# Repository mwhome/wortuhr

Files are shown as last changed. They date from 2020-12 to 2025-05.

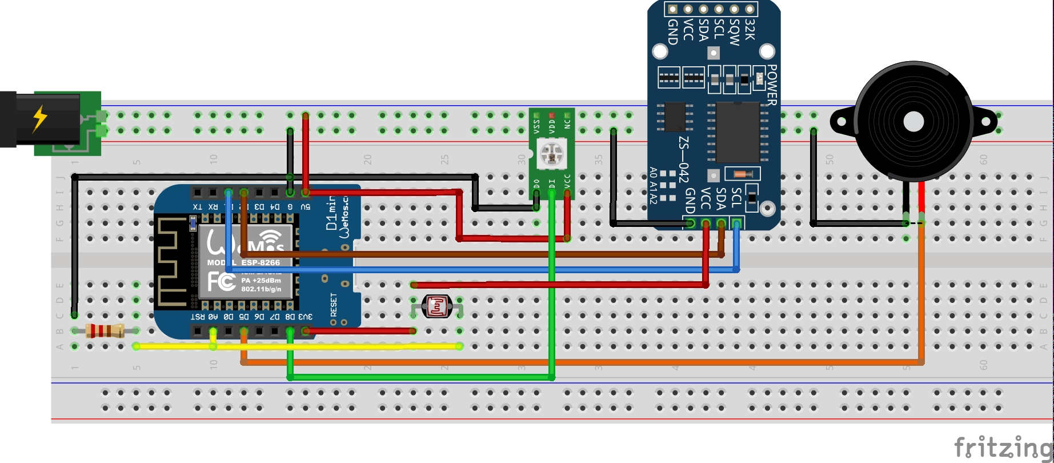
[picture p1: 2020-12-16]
ZeichnungenBilder/WordClockWlankomplett_Steckplatine.jpg

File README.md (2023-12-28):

# wortuhr
Eine Wortuhr auf Basis der Qlockwork von https://github.com/ch570512/Qlockwork und 
https://github.com/bracci/Qlockwork mit verändertem Layout. die ersten LEDs sind die Minuten unten mittig und dann von rechts unten nach rechts oben.

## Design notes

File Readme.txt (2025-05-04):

******************************************************************************
QLOCKWORK
An advanced firmware for a DIY "word-clock".
******************************************************************************

Qlockwork is an ESP8266 (NodeMCU or WeMos D1 mini) firmware (under GPL license) for a so called "word-clock",
initially implemented by ch570512 (thanks Thorsten) and evolved by bracci.

The clock adjusts the time and date once every hour via NTP with a time server on the Internet.
If an RTC is installed, the time of the ESP is also set from the RTC via the SyncProvider.

At startup the clock performs a short self test.
The sequence of the colors should be: red, green, blue and white. If not, your LED driver setup is wrong.
The clock also shows the local IP address it received via DHCP.
Use this address in a browser to access the clocks web site to set it up.

WiFi manager: If the clock can not connect to any WLAN at startup, it turns on an access point(AP).
Connect a mobile phone or tablet to the AP and enter the WLAN credentials. A white "WiFi" is shown on the clock.
On success there are three short beeps and "WiFi" will be green.
If no WLAN is connected or the timeout has expired, there is a long beep and "WiFi" turns red.
After the WLAN timeout the clock works without NTP but you can still control it via its AP.
Without WLAN the clock uses the optional RTC to set the time or if no RTC is present has to be set manually.
In either ways the clocks IP is shown as a textfeed.

WPS: First press the WPS button on your WLAN router, then press the mode button on the QlockWiFive for more than 
5 seconds. While keeping the menu button pressed, don't get confused about the mode first increments (e.g. seconds),
then after 2s jumps to settings and only after 5 seconds "WPS" is shown in blue color on the clock display. Release
the button and wait. On success "WPS" will turn green. At failure it turns red.

Events can be shown at a certain repetition rate (every 5/15/30/60 minutes) on a particular day of the year as an 
animation (e.g. a firework) followed by a textfeed. Up to 8 events can be configured through the web interface. 
Go to settings (gear icon) -> events (birthday cake icon). You can set a text and color as well as an animation
and the desired repetition rate for every event.

Up to 30 animation files (examples in folder /data) can be stored on the file system to be selected and
played on events. Code snippets and files used from manfred-hofmann (thanks Manfred).

Updates of the firmware could be uploaded via USB, OTA or the clocks webserver.
You will find more help and information on how to configure and compile the firmware in "Readme.md" in the zip-archive.
You will also find a circuit diagram, a partslist and some pictures in the "/misc" directory.
All sensors, the RTC and the buzzer are optional.
The clock can run even with an ESP8266 module only.

Warning:    Do not power up the clock from USB only.
            This would blow up the ESP or even the USB port because of high power demand of the LED stripe.
            Always use an external 5V powersupply with at least 3A.

Disclaimer: Qlockwork uses lots of third party libraries.
            We can not guarantee the integrity of these libraries.
            You use the Qlockwork firmware at your own risk.

You can find some more information about QLOCKWORK here:
http://thorsten-wahl.ch/qlockwork/

You can download the latest version of the firmware here:
https://github.com/bracci/Qlockwork

Shop Hardware here:
https://shop.bracci.ch/

Visit this forum for comments, suggestions and bug reports:
http://diskussion.christians-bastel-laden.de/viewtopic.php?t=4230 (QlockWiFive)
http://diskussion.christians-bastel-laden.de/viewtopic.php?f=23&t=2843 (Qlockwork)

******************************************************************************
Top features:
******************************************************************************

Almost no electronics needed. Only an ESP8266 and an LED-stripe.
Optional support for LDR/photo transistor, buzzer, temperature and humidity sensor, IR sensor/remote and buttons.
Support for NeoPixel (RGB and RGBW) LED-stripes.
Support for various horizontal and vertical LED layouts. 5 layouts included.
Webpage to control and configure the clock via WiFi.
WPS functionality for a quick and easy WiFi setup.
Settings via on-screen menu using tactile buttons or IR-remote to control.
Adaptive brightness control when using an LDR or photo transistor.
3 transitions for timechange.
Indoor temperature from RTC, MCP9808 or BME280 or temperature and humidity from DHT or BME280 sensor.
Outdoor temperature and humidity from OpenWeather. You need an APIKey from OpenWeather to use this feature.
Visualisation of moonphase.
Show sunrise and sunset times with animation.
Textfeed and animations for 8 custom events and infos.
Upload up to 30 animation files, usable for events.
Support for 16 frontcovers (original and DIY) in 6 languages.
25 colors.
3 color change modes (incl. mood light -> continuous color change)
99 minute timer.
2 Alarms with weekday selection.
NTP timesync with timezone support.
Automatic adjustment of daylight saving time.
USB and over-the-air firmware updates.
Admin settings page to configure time server, OpenWeather API key & location and the front cover.

******************************************************************************
Pages:
******************************************************************************

Modes:
Time
AM/PM
Seconds
Weekday
Date
Sunrise (needs OpenWeather)
Sunset (needs OpenWeather)
Moonphase
Room temperature (needs RTX or DHT22)
Room humidity (needs DHT22)
Outdoor temperature (needs OpenWeather)
Outdoor humidity (needs OpenWeather)
Timer
LED-test
Red
Green
Blue
White

Settings:
Auto brightness control
Color
Color change
Transition
IT IS
Time
Year
Month
Day
Daily switch off time
Daily switch on time
Fallback timeout back to time

******************************************************************************
Needed libraries: (recommended/tested versions in brackets)
******************************************************************************

Arduino IDE for Windows (1.8.57)
esp8266 by ESP8266 Community (3.1.2)
Arduino_JSON by Arduino (0.1.0)
Adafruit NeoPixel by Adafruit (1.11.0)
Adafruit Unified Sensor by Adafruit (1.1.9)
Adafruit MCP9808 by Adafruit (2.0.0)
Adafruit BME280 by Adafruit (2.4.1)
ArduinoHttpClient by Arduino (0.4.0)
ArduinoOTA by Juraj Andressy (1.0.7)
DHT sensor library by Adafruit (1.4.3)
DS3232RTC by Jack Christensen (2.0.0)
IRremoteESP8266 by Sebastien Warin (2.8.4)
Time by Paul Stoffregen (1.6.1)
WiFiManager by tablatronix/tzapu (0.16.0)
Timezone by Jack Christensen (1.2.4)

******************************************************************************
Compiler-Options: (recommended/tested)
******************************************************************************

Board: "LOLIN(WEMOS) D1 R2 & mini"
CPU Frequency: "80 MHz"
Flash Size: "4M (3M SPIFFS)"
Debug port: "Disabled"
Debug Level: "None"
IwIP Variant: "v2 Lower Memory"
VTables: "Flash"
Exceptions: "Disabled"
Erase Flash: "Only Sketch"
SSL Support: "All SSL ciphers"

******************************************************************************
Misc:
******************************************************************************

For OTA and web-server updates check out:
http://esp8266.github.io/Arduino/versions/2.3.0/doc/ota_updates/readme.html
Don't forget to install Python 2.7 and to select "Add python.exe to path" while installing.

Call "http://your_clocks_ip/update" to upload a new firmware via webbrowser.
Call "http://your_clocks_ip/reset" to restart the ESP.
Call "http://your_clocks_ip/wifiReset" to forget all WiFi networks and credentials.
Call "http://your_clocks_ip/settingsReset" to forget all settings.
Call "http://your_clocks_ip/factoryReset" to forget all settings, WiFi networks and credentials.
Call "http://your_clocks_ip/admin" to open the admin settings page.
Call "http://your_clocks_ip/fs" to open the file system on the ESP and upload animation files, e.g. stored in the repository in the folder "web".

******************************************************************************
Operation manual:
******************************************************************************

Press "on/off" to switch the LEDs on and off.
Press "Settings" to configure the clock via web-site.
Press "Mode" to jump to the next page. Long press enters settings menu. (if enabled by SHOW_MODE_SETTINGS)
Press "Time" to always jump back to the time page.
Press "Plus" to increase LED brightness or to increment value/switch options in settings menu.
Press "Minus" to decrease LED brightness or to decrement value/switch options in settings menu.

*** Modes: *******************************************************************

Time:                               The default mode of the clock. Shows the actual time. :)
Display AM/PM:                      Indicates whether it is AM or PM.
Seconds:                            Shows the seconds.
Weekday:                            Shows the weekday in local language.
Date:                               Shows day and month.
Sunrise:                            Time of sunrise.
Sunset:                             Time of sunset.
Moonphase:                          Shows the moonphase.
Room temperature:                   Display of the measured temperature in the room (only with RTC, MCP9808, BME280 or DHT22).
Room humidity:                      Display of the measured humidity in the room (only with BME280 or DHT22).
Outdoor temperature:                Display the temperature for your location from OpenWeather.
Outdoor humidity:                   Display the humidity for your location from OpenWeather.
Timer:                              Display of the remaining time if a timer is set.
LED-Test:                           Moves a horizontal bar across the display.
Red:                                Set all LEDs to red.
Green:                              Set all LEDs to green.
Blue:                               Set all LEDs to blue.
White:                              Set all LEDs to white.

*** Settings (on-screen): ***************************************************

Auto brightness control (AB):		Enable (EN) or disable (DA) adaptive brightness control.
                                    Brightness will adjust itself in the range of MIN_BRIGHTNESS and brightness.
Color (CO):							Choose one of 25 colors (0~25) for the LEDs.
Color change (CC):					Change the color in intervals.
                                    Do not change (NO), every 5 minutes (5), every hour (60), every day (24), continuously (MD).
Transition (TR):					Choose between none (NO), matrix (MX), move up (UP) or fade (FD) mode transition.
Purist Mode (PT):					Enable (EN) or disable (DA) purist mode. It will be shown every half and full hour anyway.
Show "GSI" (GS):					Enable (EN) or disable (DA) the term GSI for swiss german.
Time (TI ME):						Set the current time in case no internet connectivity is available. The seconds are set to zero.
Year (YY):							Set the current year in case no internet connectivity is available.
Month (MM):							Set the current month in case no internet connectivity is available.
Day (DD):							Set the current day in case no internet connectivity is available.
Daily switch off time (DO FF):		Set the time at which the clock switches off automatically (e.g. at the evening).
Daily switch on time (D ON):		Set the time at which the clock switches on automatically (e.g. at the morning).
Fallback timeout (FB):				Time in seconds to change mode back to time. (0: disabled, max. 60s)

*** Settings (web): **********************************************************

Alarm 1:                            Enable (on) or disable (off) alarm 1.
                                    Time for alarm 1.
                                    Weekdays on which alarm 1 is active.
Alarm 2:                            Enable (on) or disable (off) alarm 2.
                                    Time for alarm 2.
                                    Weekdays on which alarm 2 is active.
Hourly beep:                        Short beep every full hour.
Timer:                              Sets the minute timer. Set to zero to disable a running timer.
Show temperature:                   Enable (on) or disable (off) showing the temperature in time view.
Auto brightness control:      		Enable (on) or disable (off) adaptive brightness control.
                                    Brightness will adjust itself in the range of MIN_BRIGHTNESS and brightness.
Brightness:                         Brightness of the LEDs in percent. The range is MIN_BRIGHTNESS to MAX_BRIGHTNESS.
                                    If ABC is enabled this is the maximum achievable brightness.
Color:                              Choose one of 25 colors for the LEDs.
Colorchange:                        Change the color in intervals.
                                    Do not change (off), every 5 minutes (five), every hour (hour), every day (day), continuously (mood).
Transition:                         Choose between fast, move or fade mode transition.
Fallback timeout:           		Time in seconds to change mode back to time. (0: disabled, max. 60s)
Daily switch off time:              Set the time the clock turns itself off at night.
Daily switch on time:               Set the time the clock turns itself on at day.
Purist Mode:                       	Enable (on) or disable (off) purist mode. It will be shown every half and full hour anyway.
Show "GSI":							Enable (on) or disable (off) the term GSI for swiss german.
Set date/time:                      Date and time of the clock. The seconds are set to zero if you press save.

*** Admin Settings (web): ****************************************************
Time server:						URL of the preferred time server
OpenWeather API key:				API key provided by Openweather allowing to get weather information through API.
OpenWeather location				Location which the weather information should refer to. Needs to follow the location format of 
									OpenWeather, e.g. "Bern, CH". Check out on https://openweathermap.org/ and check for your city.
Language/dialect:					Language or dialect of the used front cover.
Light sensor column no.				Column number in which the light sensor is installed.			
Light sensor row no.				Row number in which the light sensor is installed.

******************************************************************************
Configuration.h - Software settings:
******************************************************************************

#define PRODUCT_NAME                The name of the clock.
#define WEBSITE_TITLE               Title on top of the clocks webpage.
#define WIFI_SETUP_TIMEOUT          Time in seconds set up the WiFiManager or search for a WLAN.
                                    If no WLAN is connected the clock enters AP mode.
                                    You can control the clock if you connect your phone or tablet to this accesspoint.
                                    On Android you have to tell the phone that it's ok to have no internet.
#define WIFI_AP_PASS                The password for the AP. At least 8 characters. Default is "12345678".
#define OTA_PASS                    Password for "Over the Air" updates. Default is "1234".
#define NTP_SERVER                  NTP server to be queried.
#define NTP_TIMEOUT                 Milliseconds to wait for NTP server to answer.
#define WIFI_BEEPS                  Beep 3 times if WIFI is conneced, if not, beep one time on startup.
#define SHOW_IP                     Show local IP at startup. Use this in the browser to access the clocks menue.
#define NONE_TECHNICAL_ZERO         Displays the zero without the diagonal line.
#define AUTO_MODECHANGE_TIME        Time in seconds to wait between switching from time to temperature.
#define FEED_SPEED                  Feed delay in milliseconds. 120 is a good start.
#define SUNSET_SUNRISE_SPEED        Milliseconds delay between sunrise screen -> sunrise time and sunset screen -> sunset time
#define ALARM_LED_COLOR             Color of the alarm LED. If not defined the display color will be used.
                                    The possible colors are:
                                    WHITE, RED, RED_25, RED_50, ORANGE, YELLOW, YELLOW_25, YELLOW_50, GREENYELLOW,
                                    GREEN, GREEN_25, GREEN_50, MINTGREEN, CYAN, CYAN_25, CYAN_50, LIGHTBLUE, BLUE,
                                    BLUE_25, BLUE_50, VIOLET, MAGENTA, MAGENTA_25, MAGENTA_50, PINK.
#define ABUSE_CORNER_LED_FOR_ALARM  Use the upper right minute LED as alarm LED. Only works if ALARM_LED_COLOR is defined.
                                    If no alarm or timer is set the LED is used as expected.
#define DEDICATION                  Show a text on the clocks webpage.

#define POWERON_SELFTEST            Test LEDs at startup. Colors are: white, red, green, blue. In this order.
#define SHOW_MODE_AMPM              Show AM/PM.
#define SHOW_MODE_SECONDS           Show seconds.
#define SHOW_MODE_WEEKDAY           Show weekday.
#define SHOW_MODE_DATE              Show date.
#define SHOW_MODE_MOONPHASE         Show moonphase.
#define SHOW_MODE_SUNRISE_SUNSET    Show sunrise and sunset times.
#define SHOW_MODE_TEST              Show tests.
#define SHOW_MODE_SETTINGS	        Show on-display settings menu.

#define APIKEY                      Enables OpenWeather features.
#define DEFAULT_LOCATION            Default location for OpenWeather.

#define TIMEZONE_*                  The time zone in which the clock is located. Important for the UTC offset and the
                                    summer/winter time change.
#define LANGUAGE_*					Language of the web interface.

******************************************************************************
Configuration.h - Hardware settings:
******************************************************************************

#define ESP_LED                     Displays the function using the LED on the ESP. It flashes once a second.

#define ONOFF_BUTTON                Use a hardware on/off-button.
#define MODE_BUTTON                 Use a hardware mode-button.
#define TIME_BUTTON                 Use a hardware time-button.
#define PLUS_BUTTON					Use a hardware plus-button.
#define MINUS_BUTTON				Use a hardware minus-button.

#define SENSOR_DHT22                Use a DHT22 sensor module (not the plain sensor) for room temperature and humidity.
#define DHT_TEMPERATURE_OFFSET      Sets how many degrees the measured room temperature (+ or -) should be corrected.
#define DHT_HUMIDITY_OFFSET         Sets how many degrees the measured room humidity (+ or -) should be corrected.

#define SENSOR_MCP9808				Use a MCP9808 sensor or sensor module.
#define MCP_TEMPERATURE_OFFSET		Sets how many degrees the measured room temperature (+ or -) should be corrected.

#define SENSOR_BME					Use a BME280 sensor or sensor module.
#define BME_TEMPERATURE_OFFSET		Sets how many degrees the measured room temperature (+ or -) should be corrected.
#define BME_HUMIDITY_OFFSET         Sets how many degrees the measured room humidity (+ or -) should be corrected.

#define RTC_BACKUP                  Use an RTC as backup and room temperature.
#define RTC_TEMPERATURE_OFFSET      Sets how many degrees the measured room temperature (+ or -) should be corrected.

#define LDR                         Use an LDR for adaptive brightness control (ABC).
#define LDR_IS_INVERSE              Combined with #define LDR inverses the value of the LDR.
#define LDR_HYSTERESIS              Brightness control from a deviation in the range from 0 to 1023. Default: 40.
                                    If your display is flickering increase this value.
#define MIN_BRIGHTNESS              Minimum brightness of LEDs ranging from 0 to 255. Default: 20.
#define MAX_BRIGHTNESS              Maximum brightness of LEDs ranging from 0 to 255. Default 255.
                                    Your powersupply has to support this brightness.
#define BRIGHTNESS_SELFTEST         Brightness of the LEDs while in testmode to not overload the powersupply.

#define BUZZER                      Use a buzzer to make noise for alarmtime and timer.
                                    If not defined all alarmfunctions are disabled.
#define BUZZTIME_ALARM_1            Maximum time in seconds for alarm 1 to be active when not turned off manually.
#define BUZZTIME_ALARM_2            Maximum time in seconds for alarm 2 to be active when not turned off manually.
#define BUZZTIME_TIMER              Maximum time in seconds for the timer alarm to be active when not turned off manually.

#define IR_REMOTE                   Use an IR remote control.
#define IR_LETTER_OFF               Turns off the LED behind the IR sensor permanently. This improves IR reception.
#define IR_CODE_*                   Any remote control can be used. 6 keys are supported.
                                    Press a button on the remote control in front of the clock.
                                    Then write the code displayed in the serial console to the file "Configuration.h".
                                    If you see more than one try the code which is changing from button to button.
                                    DEBUG has to be defined to show you the code.

#define NEOPIXEL_RGB                Select if your LEDs are RGB only.
#define NEOPIXEL_RGBW               Select if your LEDs have a distinct white channel (RGBW).

#define NEOPIXEL_TYPE               Specifies the NeoPixel driver. 400kHz, 800kHz, GRB, RGB, GRBW, RGBW...
                                    See \libraries\Adafruit_NeoPixel.h for help.

#define LED_LAYOUT_HORIZONTAL_1     Horizontal and corner and alarm LEDs at the end of the strip. (As seen from the front.)

111                    114                    112
   000 001 002 003 004 005 006 007 008 009 010
   021 020 019 018 017 016 015 014 013 012 011
   022 023 024 025 026 027 028 029 030 031 032
   043 042 041 040 039 038 037 036 035 034 033
   044 045 046 047 048 049 050 051 052 053 054
   065 064 063 062 061 060 059 058 057 056 055
   066 067 068 069 070 071 072 073 074 075 076
   087 086 085 084 083 082 081 080 079 078 077
   088 089 090 091 092 093 094 095 096 097 098
   109 108 107 106 105 104 103 102 101 100 099
110                                           113

#define LED_LAYOUT_VERTICAL_1       Vertical and corner and alarm LEDs (almost) within the strip. (As seen from the front.)

000                    114                    102
   001 021 022 041 042 061 062 081 082 101 103
   002 020 023 040 043 060 063 080 083 100 104
   003 019 024 039 044 059 064 079 084 099 105
   004 018 025 038 045 058 065 078 085 098 106
   005 017 026 037 046 057 066 077 086 097 107
   006 016 027 036 047 056 067 076 087 096 108
   007 015 028 035 048 055 068 075 088 095 109
   008 014 029 034 049 054 069 074 089 094 110
   009 013 030 033 050 053 070 073 090 093 111
   010 012 031 032 051 052 071 072 091 092 112
011                                           113

#define LED_LAYOUT_VERTICAL_2       Vertical and corner and alarm LEDs at the end of the strip. (As seen from the front.)

112                    111                    110
   009 010 029 030 049 050 069 070 089 090 109
   008 011 028 031 048 051 068 071 088 091 108
   007 012 027 032 047 052 067 072 087 092 107
   006 013 026 033 046 053 066 073 086 093 106
   005 014 025 034 045 054 065 074 085 094 105
   004 015 024 035 044 055 064 075 084 095 104
   003 016 023 036 043 056 063 076 083 096 103
   002 017 022 037 042 057 062 077 082 097 102
   001 018 021 038 041 058 061 078 081 098 101
   000 019 020 039 040 059 060 079 080 099 100
113                                           114

#define LED_LAYOUT_VERTICAL_3       Vertical and corner and alarm LEDs at the end of the strip. (As seen from the front.)

111                    114                    110
   009 010 029 030 049 050 069 070 089 090 109
   008 011 028 031 048 051 068 071 088 091 108
   007 012 027 032 047 052 067 072 087 092 107
   006 013 026 033 046 053 066 073 086 093 106
   005 014 025 034 045 054 065 074 085 094 105
   004 015 024 035 044 055 064 075 084 095 104
   003 016 023 036 043 056 063 076 083 096 103
   002 017 022 037 042 057 062 077 082 097 102
   001 018 021 038 041 058 061 078 081 098 101
   000 019 020 039 040 059 060 079 080 099 100
112                                           113

#define LED_LAYOUT_VERTICAL_4       Vertical and corner and alarm LEDs at the end of the strip. (As seen from the front.)
#define LED_LAYOUT_VERTICAL_4_XXL	Indentically with LED_LAYOUT_VERTICAL_4 but with 2 LEDs per letter.

011                    114                    113
   010 012 031 032 051 052 071 072 091 092 112
   009 013 030 033 050 053 070 073 090 093 111
   008 014 029 034 049 054 069 074 089 094 110
   007 015 028 035 048 055 068 075 088 095 109
   006 016 027 036 047 056 067 076 087 096 108
   005 017 026 037 046 057 066 077 086 097 107
   004 018 025 038 045 058 065 078 085 098 106
   003 019 024 039 044 059 064 079 084 099 105
   002 020 023 040 043 060 063 080 083 100 104
   001 021 022 041 042 061 062 081 082 101 103
000                                           102

#define LED_LAYOUT_VERTICAL_5       Vertical and corner and alarm LEDs (almost) within the strip. (As seen from the front.)

000                    062                    103
   001 021 022 041 042 061 063 082 083 102 104
   002 020 023 040 043 060 064 081 084 101 105
   003 019 024 039 044 059 065 080 085 100 106
   004 018 025 038 045 058 066 079 086 099 107
   005 017 026 037 046 057 067 078 087 098 108
   006 016 027 036 047 056 068 077 088 097 109
   007 015 028 035 048 055 069 076 089 096 110
   008 014 029 034 049 054 067 075 090 095 111
   009 013 030 033 050 053 071 074 091 094 112
   010 012 031 032 051 052 072 073 092 093 113
011                                           114

******************************************************************************
Configuration.h - Misc:
******************************************************************************

#define DEBUG                       Show debug infos in the serial console.
#define DEBUG_WEB                   Show debug infos on the web page.
#define DEBUG_MATRIX                Renders the output of the matrix for the German front in the serial console.
#define DEBUG_FPS                   Show number of loops per second in the serial console.

#define SYSLOGSERVER                Turn logging to a syslogserver on/off.
#define SYSLOGSERVER_SERVER         Address of the syslogserver.
#define SYSLOGSERVER_PORT           Port of the syslogserver.

#define UPDATE_INFO_*               The update info periodically anonymously checks if there is a firmwareupdate
                                    available. No user data is send to the host. Comment if you do not want this info.
#define UPDATE_INFOSERVER           Address of the updateinfo server.
#define UPDATE_INFOFILE             Path and name of the updateinfo file.

#define SERIAL_SPEED                Serial port speed for the console.

******************************************************************************
Web-API:
******************************************************************************

http://your_clocks_ip/commitSettings?
a1=0                                Alarm 1 on [1] or off [0]
a1t=hh:mm                           Alarm 1 hour [hh] and minute [mm]
a1w1=2                              Set Sunday
a1w2=4                              Set Monday
a1w3=8                              Set Tuesday
a1w4=16                             Set Wednesday
a1w5=32                             Set Thursday
a1w6=64                             Set Friday
a1w7=128                            Set Saturday
a2=0                                Alarm 2 on [1] or off [0]
a2t=hh:mm                           Alarm 2 hour [hh] and minute [mm]
a2w1=2                              Set Sunday
a2w2=4                              Set Monday
a2w3=8                              Set Tuesday
a2w4=16                             Set Wednesday
a2w5=32                             Set Thursday
a2w6=64                             Set Friday
a2w7=128                            Set Saturday
hb=0                                Hourly beep on [1] or off [0]
ti=0                                Timer in minutes
mc=0                                Modechange on [1] or off [0]
ab=1                                ABC on [1] or off [0]
br=50                               Brightness in percent
co=14                               Number of the LEDs color. See Colors.h
cc=0                                Number of colorchange. See Colors.h
tr=1                                Number of transition. See Modes.h
to=15                               Timeout in seconds
no=hh:mm                            Night off hour [hh] and minute [mm]
do=hh:mm                            Day on hour [hh] and minute [mm]
ii=1                                Purist mode on [1] or off [0]
gs=0								Enable [1] or disable [0] the term GSI for swiss german
st=YYYY-MM-DDThh:mm                 Set time and date

http://your_clocks_ip/commitEvents?
ev0t=Happy+Birthday					Feed text (max. 30 characters) for event no.0
ev0ani=0							Animation name [0~29] for event no.0
ev0d=YYYY-MM-DD						Date for event no.0
ev0c=0								Color [0~24] for event no.0
ev0rep=4							Repetition rate [0~4] for event no.0
...
ev0t=Happy+Birthday					Feed text (max. 30 characters) for event no.7
ev0ani=0							Animation name [0~29] for event no.7
ev0d=YYYY-MM-DD						Date for event no.7
ev0c=0								Color [0~24] for event no.7
ev7rep=4							Repetition rate [0~4] for event no.7

http://your_clocks_ip/commitAdminSettings?
adts=pool.ntp.org                   URL of preferred time server
adwk=123...                         API key used for OpenWeather
adwl=bern, ch						Openweather location
adfc=0								Front cover [0~13]

http://your_clocks_ip/showText?
buzzer=1                            Number of times the buzzer will beep before showing the text (optional)
color=0                             Color of the textfeed, 0 to 24 (optional)
text=text                           Set text of feed, max. 80 characters
                                    e.g.: http://192.168.1.10/showText?buzzer=2&color=1&text=Instant%20text%20on%20Qlockwork!

http://your_clocks_ip/control?
mode=0                              Set clock to mode=0 (time), mode=1 (am/pm), ...
                                    mode=17 (off, if all other modes are enabled) -- see modes.h and count.
                                    e.g.: http://192.168.1.10/control?mode=6

******************************************************************************
Changelog:
******************************************************************************
20240227:
Reverted special cases for HW v1.2. Made a separate branch (V1_2wButtons) for HW v1.2 which uses buttons.

20240214:
Added pin definitions for button and buzzer on HW v1.2.

20240206:
Introduced layout and board for QlockWiFive Mini v1.1.
Fixed bug in SWISS GERMAN ZH dialect.

20231219:
Introduced settingsReset and factoryReset. 

20231218:
Introduced settings for LDR position.
Fixed bug in dialect "Swiss German GR".
Added missing conditions and added web debug content for BME280.

20231124:
Introduced dialect of Sardinia.

20231026:
Introduced BME280 sensor to measure and display temperature and humidity.

20231024:
New swiss german dialect: Aargau (AG) & Graubuenden (GR). Available in the admin area.
Force WiFi not to go to any sleep mode.

20230620:
New swiss german dialect: Zurich (ZH). Available in the admin area.

20230604:
Fixed bug: color range of random color change.

20230531:
Optimized configuration. Little bug fixing.

20230530:
Watchdog optimization.

20230526:
Improoved stability and robustness against watchdog attacks. Some cosmetics to the web interface.

20230521:
GSI optional for swiss german. Renamed "IT IS" to purist mpde.

20230518:
Optimized and stabilized WiFi connectivity. WPS functionality. Brightness setting visualization.

20230514:
Admin settings accesible by calling "http://your_clocks_ip/admin". Here you can find settings which should not change open or
even never throughout the lifetime of the clock.

20230502:
Introduced on-screen settings menu, plus/minus buttons, file storage and events 
using animations (thanks Manfred), enhanced IR control (especially for QlockWiFive IR control), 
transition demo (IR), matrix transition, mood color mode, MCP9808 temperature sensor, bug fixing.  

<---bracci

--->ch570512
20220830:
Fixed the issue that adaptive brightness control (ABC) can not be disabled in settings.

20220429:
Moved the web-site from "tmw-it.ch" to "thorsten-wahl.ch"
The UPDATE_INFOSERVER also moved there. Please update your Configuration.h

20220411:
Fixed a bug causing the project not to compile in a certain configuration.
<Qlockwork.ino:1504:33: error: 'save_color_sunrise_sunset' was not declared in this scope>

20220312:
Clocks brightness from LDR is now transitioning smoothly between values.
Sunrise and sunset now uses global timeout to switch back to time.
Fixed a bug causing the RTC not to work.
Added option to select RBG or RGBW for LedDriver.
Using transition "Move up" in menus. "Fade" was not working too well.

20220311:
Fixed a bug preventing compilation using esp8266 by ESP8266 Community (3.0.2).
IDE change from VisualMicro to free Visual Studio Code.

20220310:
Mode sunrise and sunset (Thanks to GenosseFlosse).

20210422:
Reduced the watchdog resets (Thanks to espuno).

20210321:
Fixed openweather bug for more than one weathercondition (Thanks to Manfred).
Setting RTC vom Web should be LT - not UTC (Thanks to Manfred).
Clear all LEDs before exiting test pattern (Thanks to espuno).
Calculate white channel for NEO_WRGB (Thanks to Manfred).
New LED_LAYOUT_VERTICAL_3 (Like vertical 2 but alarm LED = 114).

20210224:
WLAN RSSI on WEB page in Debug.
// -30 dBm Ausgezeichnet Dies ist die maximal erreichbare und für jedes Einsatzszenario geeignete Signalstärke.
// -50 dBm Ausgezeichnet Dieser ausgezeichnete Signalpegel ist für alle Netzwerkanwendungen geeignet.
// -65 dBm Sehr gut Empfohlen für die Unterstützung von Smartphones und Tablets.
// -67 dBm Sehr gut Diese Signalstärke reicht für Voice-over-IP und Video-Streaming aus.
// -70 dBm Akzeptabel Diese Stufe ist die minimale Signalstärke um eine zuverlässige Paket-Zustellung zu gewährleisten.
// -80 dBm Schlecht Ermöglicht grundlegende Konnektivität, die Paket-Zustellung ist jedoch unzuverlässig.
// -90 dBm Sehr schlecht Meistens Rauschen, das die meisten Funktionen behindert.
//-100 dBm Am schlechtesten Nur Rauschen.

20210218:
Outdoor pressure on WEB page.
Replaced WEB page title HOSTNAME with WEBSITE_TITLE in configuration (Thanks to GenosseFlosse).

20200709:
Turn off timer when it is running.
Some localization in settings and weather.
Fixed alarm running 4 times longer than configured.
Set Hostname (Thanks to toto79).
Fixes to Buttons for esp8266 2.7.x (Thanks to toto79).
Fixes to WiFiManager for esp8266 2.7.x (Thanks to toto79).

20200112:
WEB API for Clock On/Off.

20200107:
Bugfixes.

20200101:
Outdoor weather from OpenWeatherMap.
New LED driver with LED array mapping.
Reworked Configuration.h
Switched to lean Arduino_Json.h

20191212:
Some housekeeping.

20190520:
#define WIFI_BEEPS
Fixed rare flickering in fade transition.

20190204:
Maior update of "Readme.txt"

20190106:
Removed Yahoo weather.

20190105:
Bugfix negative outdoorTemperature.
Bugfix outdoorCode not available.

20181213:
No hourly beep if clock is off.
Some small improvements.

20181101:
Settings set to defaults!
Hourly beep.
Set color of textfeed from URL.
Set color of events[0].text from URL.
Code cleanup and some minor bugfixes.

20181027:
Show textfeed from URL.

20181021:
Set events[0] from URL.
Name is back to Qlockwork (from Qlockwork2).

20180930:
Use esp8266 by ESP8266 Community Version 2.4.2
Updated included libraries.
Removed legacy support for LPD8806RGBW.
Hardwareflags in debuginfo on webpage.
If NTP-request fails, try again every minute - don't wait for an hour.
More housekeeping.

20180929:
Cleaned up libraries.

20180130:
Transition "Move up"
Rewrote some code.
Removed FastLED.
FRONTCOVER_BINARY

20180120:
Hardware mode-, on/off- and timebutton.
Moved PIN_IR_RECEIVER from D3 to D0.
Tooltips for webbuttons.
Added description of the Web-API in Readme.txt
Cleanup and bugfixes.

20171127:
Bugfixes.

20171125:
Set weekdays for alarms on web-page.
Set alarm to "on" if alarmtime is changed.
Set time, timeout, "Night off", "Day on" on web-page.
Removed settings from clock-menu which are present on web-page.
AP mode if no WLAN is connected.
"#define DEBUG" and "#define DEBUG_WEB" are back.
Switched from RestClient.h to ArduinoHttpClient.h
Moved setting of frontcover to configuration.h "#define FRONTCOVER_*"
Removed "#define LANGUAGE_*". Now set from "#define FRONTCOVER_*"
Removed experimantal DUAL-support.
Settings set to defaults.

20171111 (stable):
Cleanup and bugfixes.
New syslog format.

20171019:
Changing automode.
Bugfix for Firefox.

20171013:
Settings of alarms, colorchange, automode and show "It is" on Web-Page.
RTC is now on UTC.

20171006:
Moonphase.
Color humidity indicator.
Faster Web-GUI.
Better offline behavior.
Reset via URL.

20170929:
Adaptive Brightness Control (ABC).
New syslog logging.
Code cleanup and bugfixes.

20170312:
Inital release.

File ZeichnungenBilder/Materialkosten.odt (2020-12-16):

Materialkosten

- LED-Streifen WS2812b 5m 30LEDs pro Meter 8,00 €
- Wemos Microcontroller 1,80 €
- LDR + Widerstand 220 Ohm 0,20 €
- Drähte zur Verkabelung 1,00 €
- MDF (Lichtgitter Rückwand innerer Rahmen 2,50 €
- Rahmen 1,70 €
- Plexiglas 4,10 €
- Tonpapier 0,80 €
- Transparentpapier 0,50 €
- USB-Kabel 1,00 €

Summe 21,60 €

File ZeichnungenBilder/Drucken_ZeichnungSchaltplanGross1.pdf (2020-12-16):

+GND DIN +GND DIN +GND DIN +GND DIN +GND DIN +GND DIN +GND DIN +GND DIN +GND DIN +GND DIN

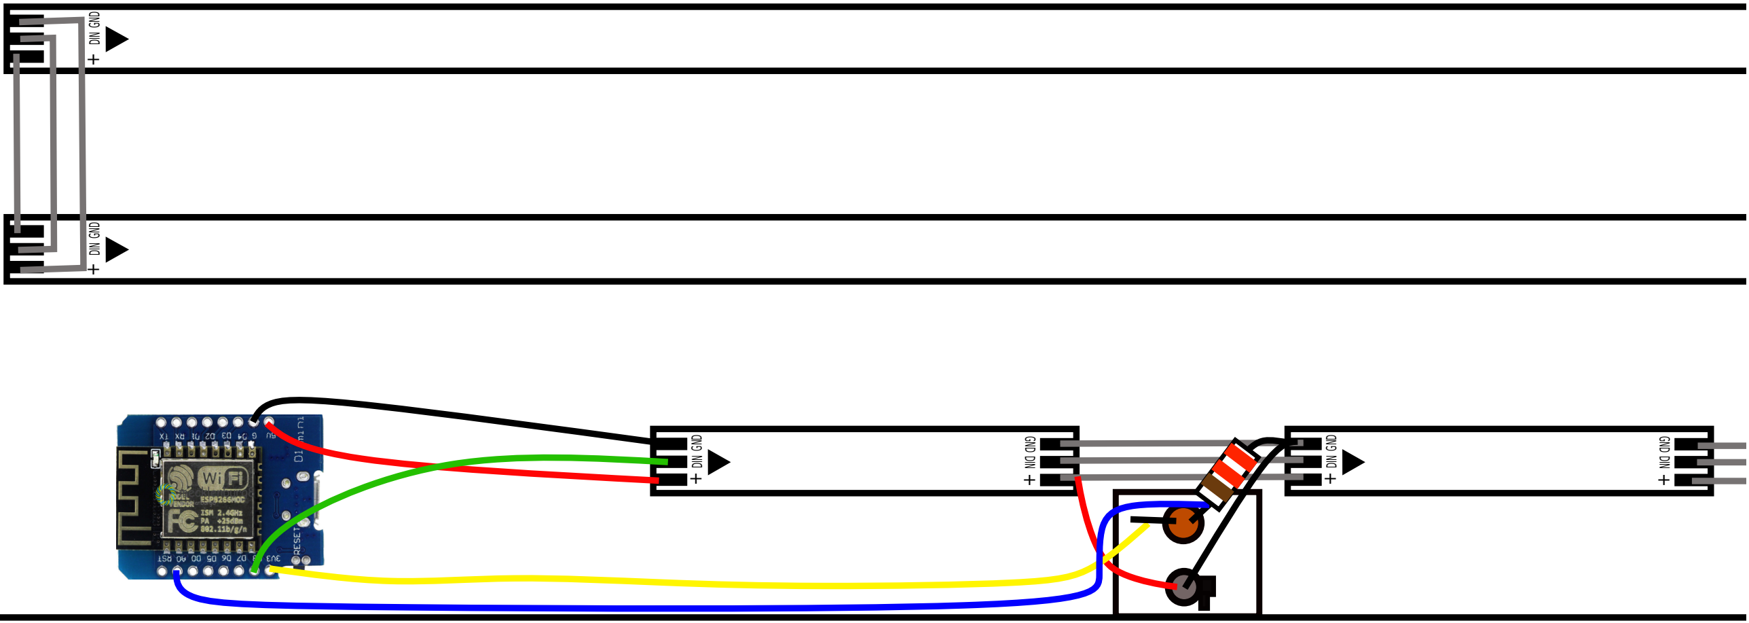
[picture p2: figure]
+GND DIN

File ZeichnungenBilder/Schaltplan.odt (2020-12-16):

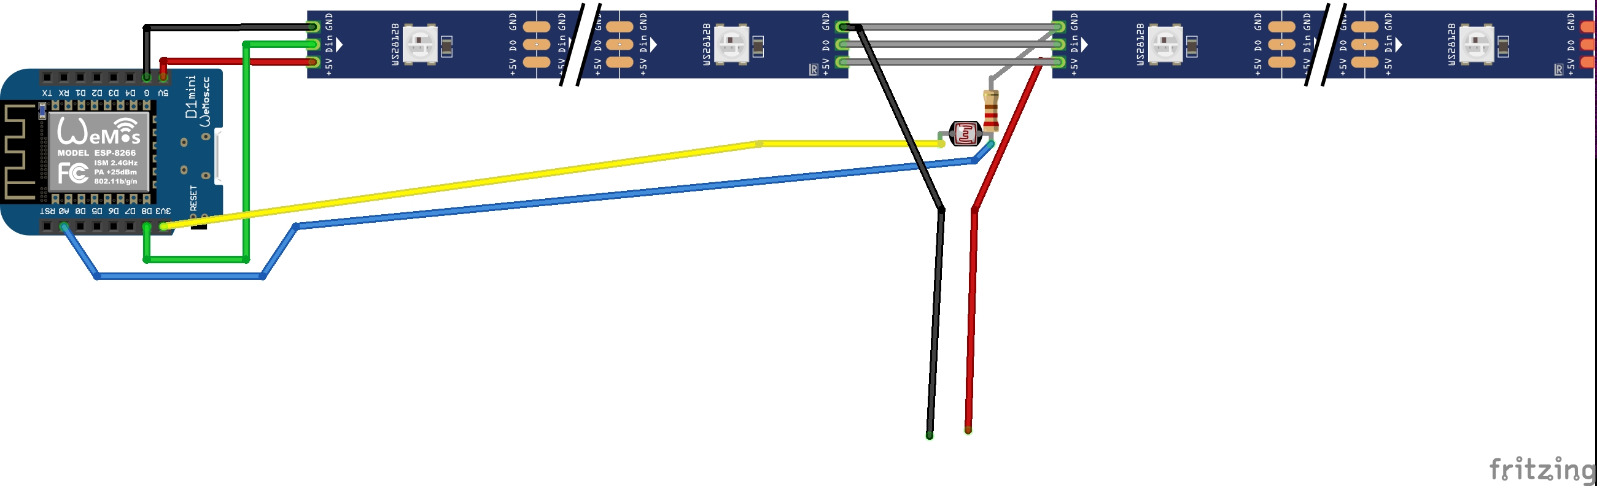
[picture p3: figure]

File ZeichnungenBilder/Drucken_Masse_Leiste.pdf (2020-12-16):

230

26

# 24 mal pro Uhr

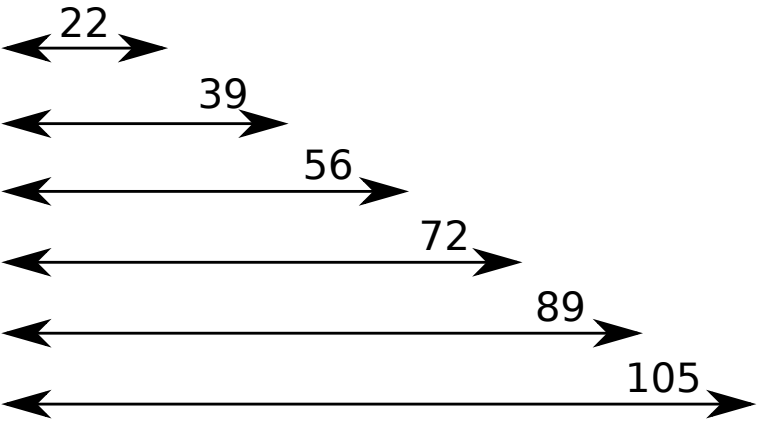
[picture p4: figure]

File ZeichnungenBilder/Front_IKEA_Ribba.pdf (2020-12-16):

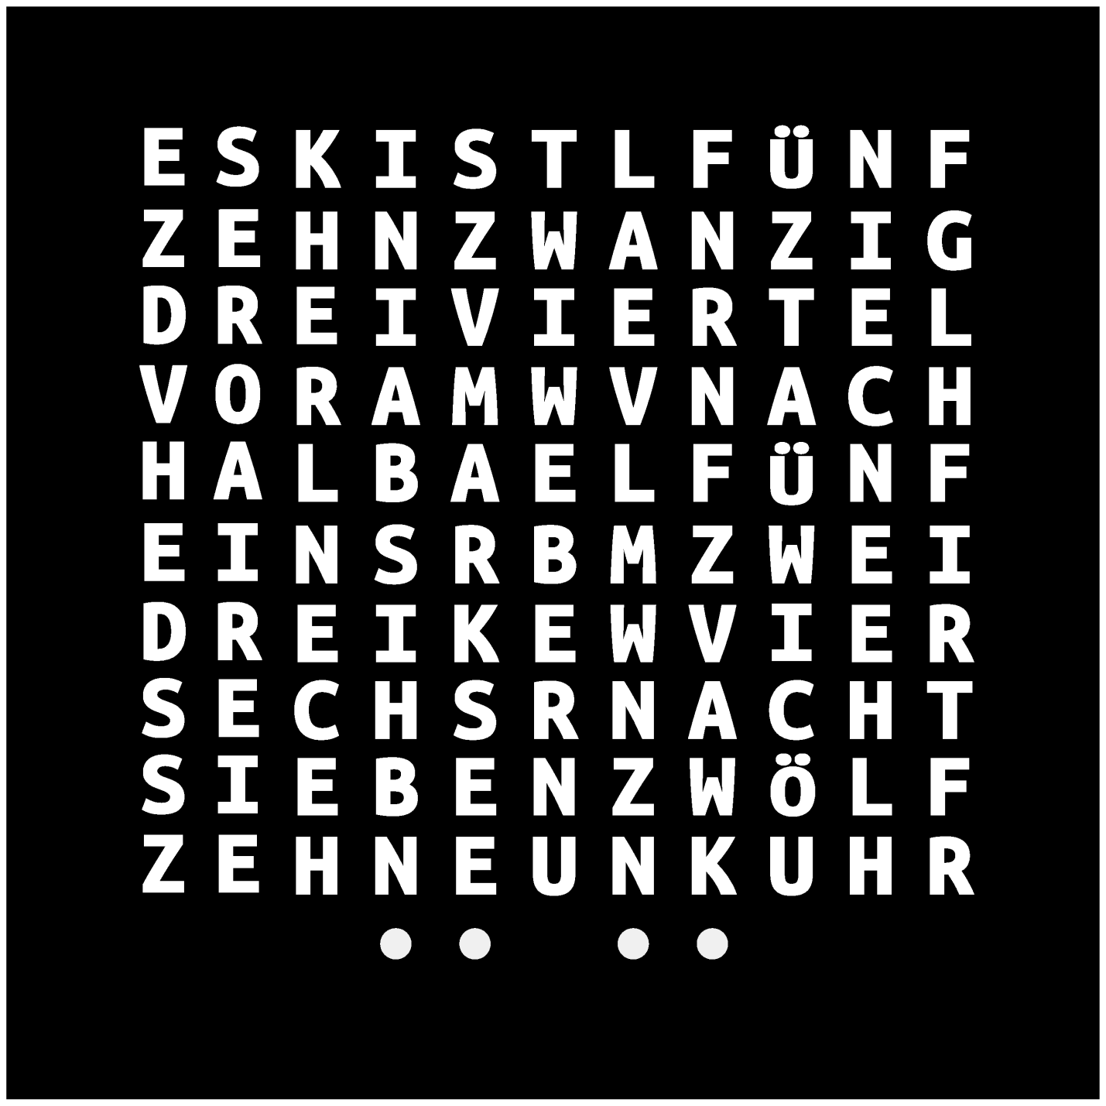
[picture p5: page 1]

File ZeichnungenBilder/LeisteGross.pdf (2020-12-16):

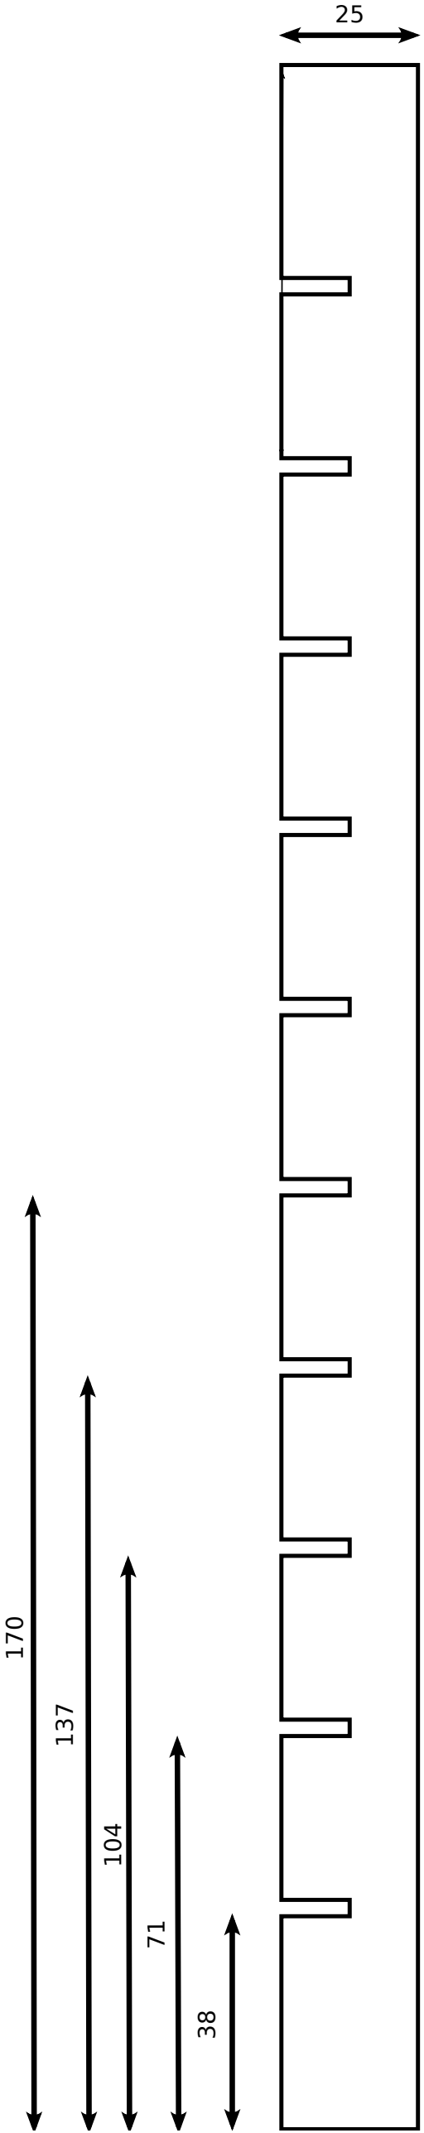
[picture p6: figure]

376

### 2 Leisten 25 mal 376

### 2 Leisten 25 mal 382

### 1 Platte 382 mal 382

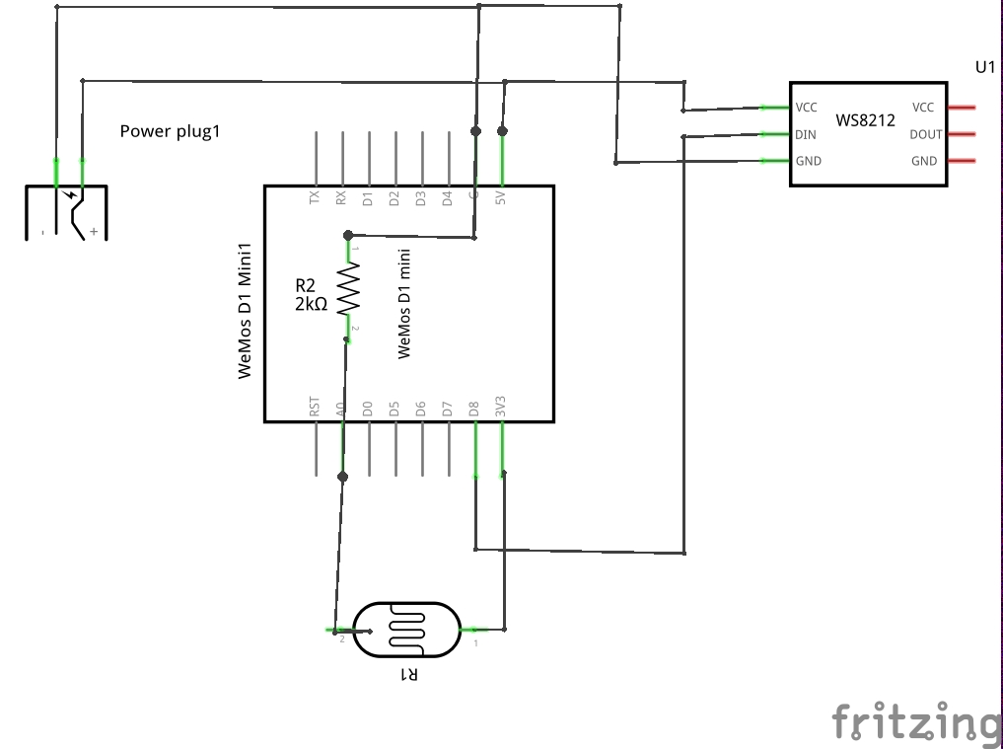
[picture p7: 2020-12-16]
ZeichnungenBilder/WordClockWlan_Schaltplan.jpg

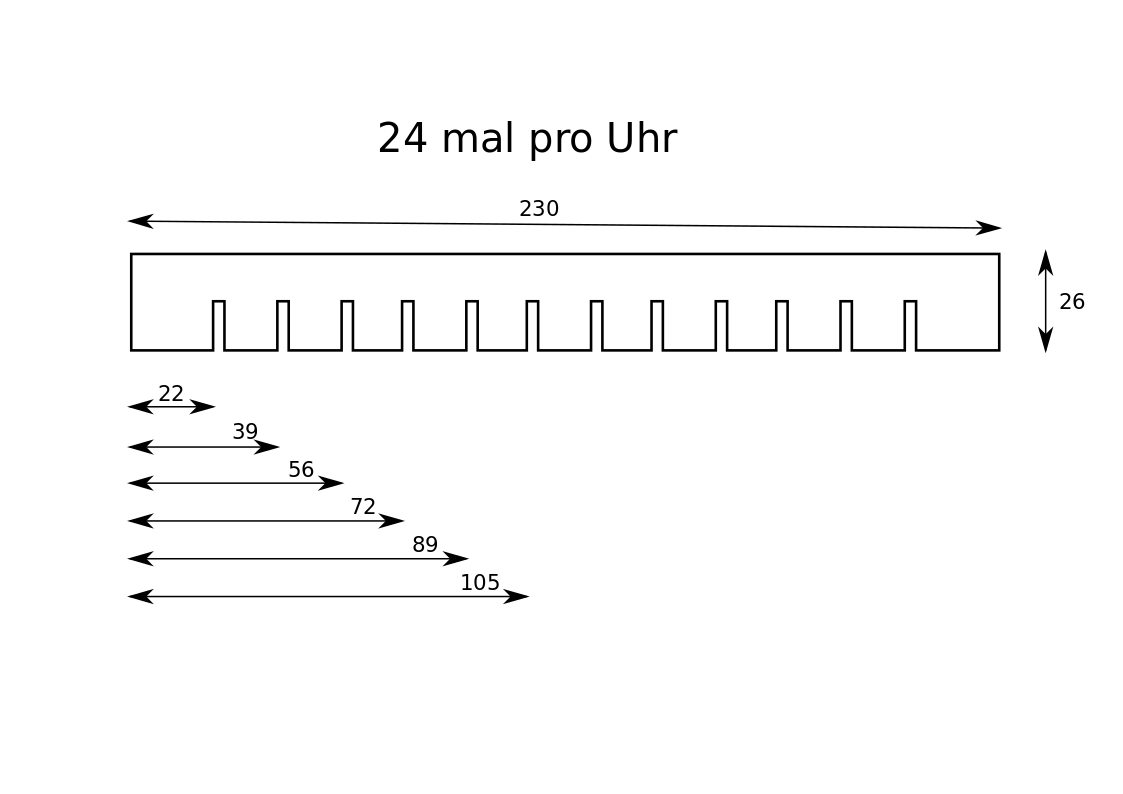
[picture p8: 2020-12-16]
ZeichnungenBilder/Masse_Leiste.png

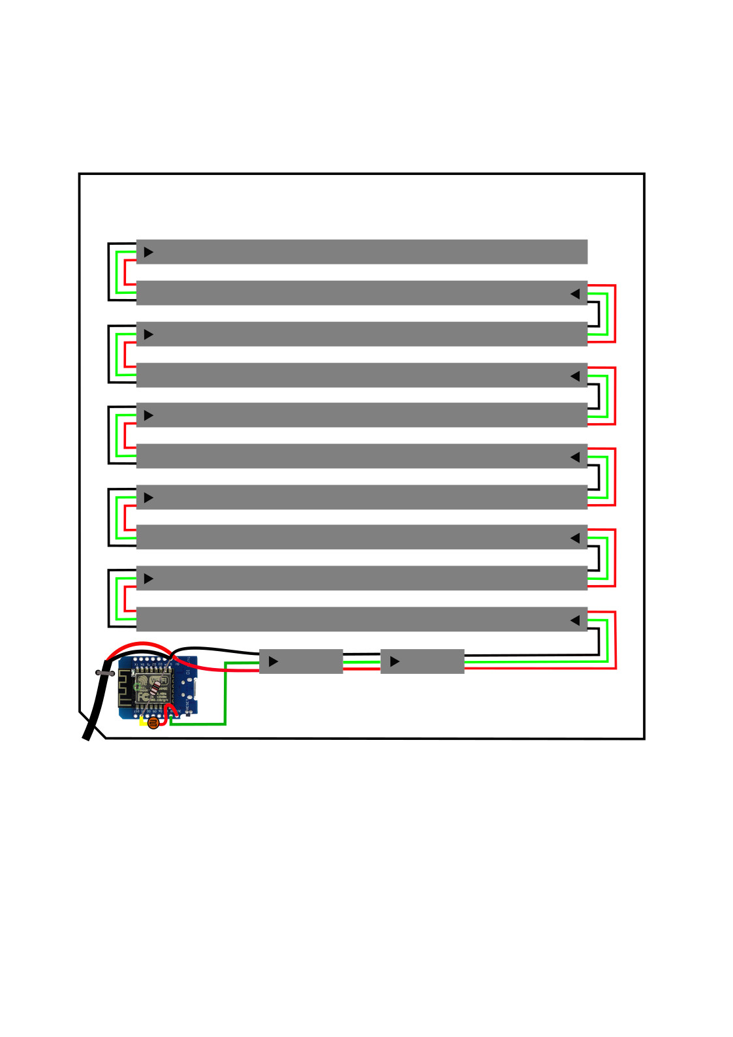
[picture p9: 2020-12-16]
ZeichnungenBilder/Rueckwand.jpg

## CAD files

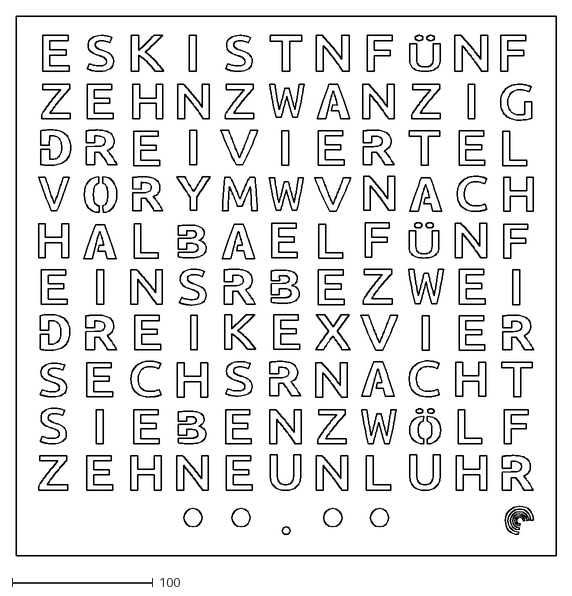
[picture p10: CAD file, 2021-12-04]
ZeichnungenBilder/ZeichnungFrontGross_SchuleAlarm.dxf
384.2 x 384.2

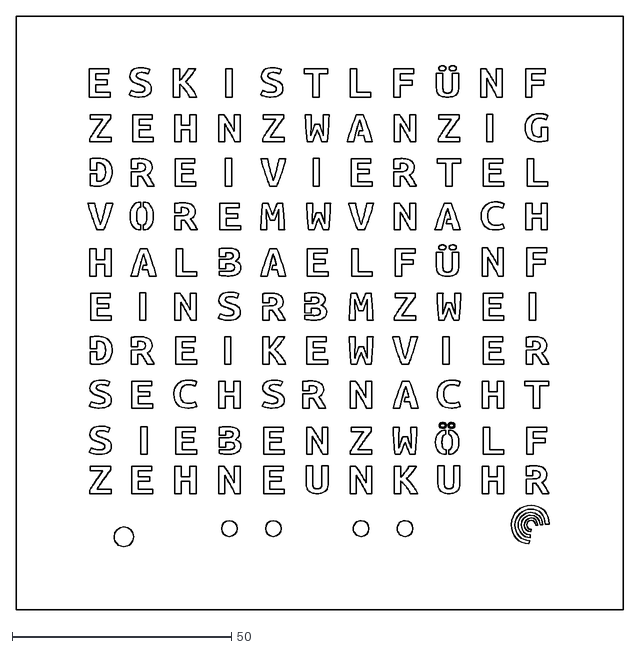
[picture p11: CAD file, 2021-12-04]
ZeichnungenBilder/Front_Wecker_Laser.dxf
138.5 x 135.4

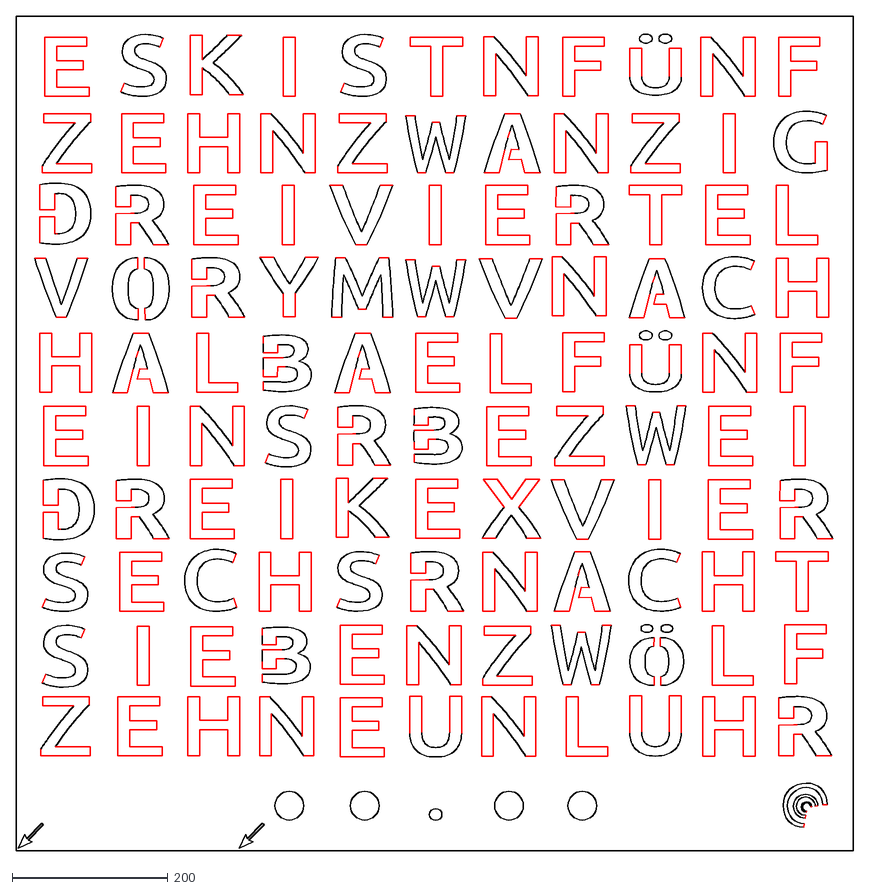
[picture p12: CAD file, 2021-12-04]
ZeichnungenBilder/ZeichnungFrontGrossAlarm.dxf
1074.6 x 1071.3

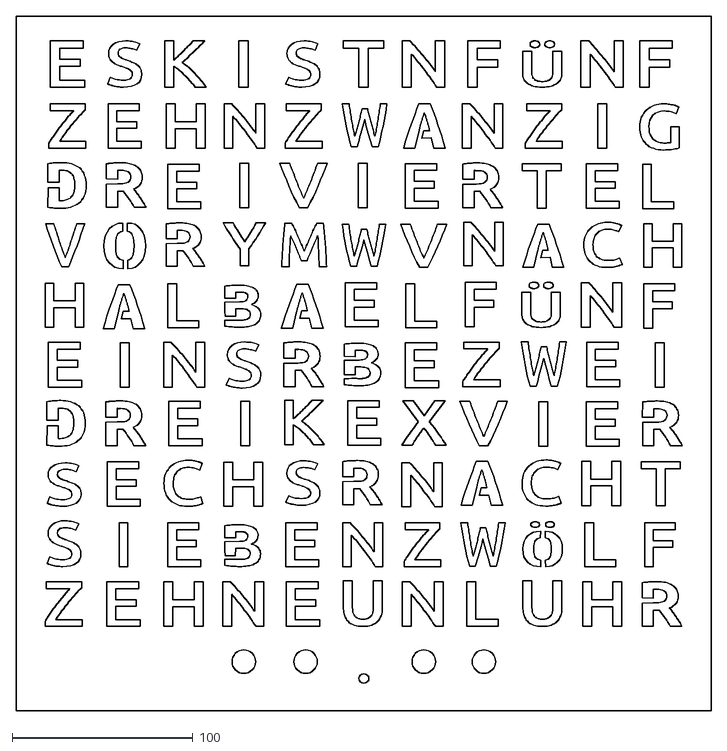
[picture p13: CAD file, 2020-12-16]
ZeichnungenBilder/ZeichnungFrontGross_Schule.dxf
384.2 x 384.2

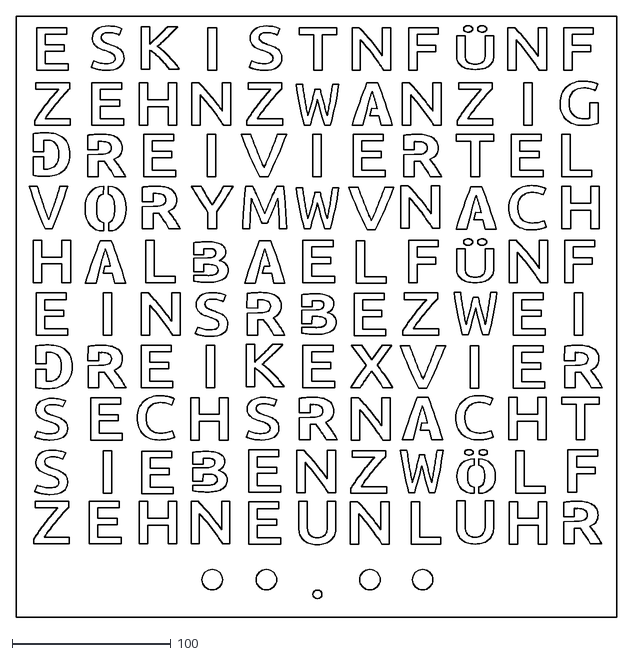
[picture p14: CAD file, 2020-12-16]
ZeichnungenBilder/ZeichnungFrontGross2.dxf
379.1 x 379.2

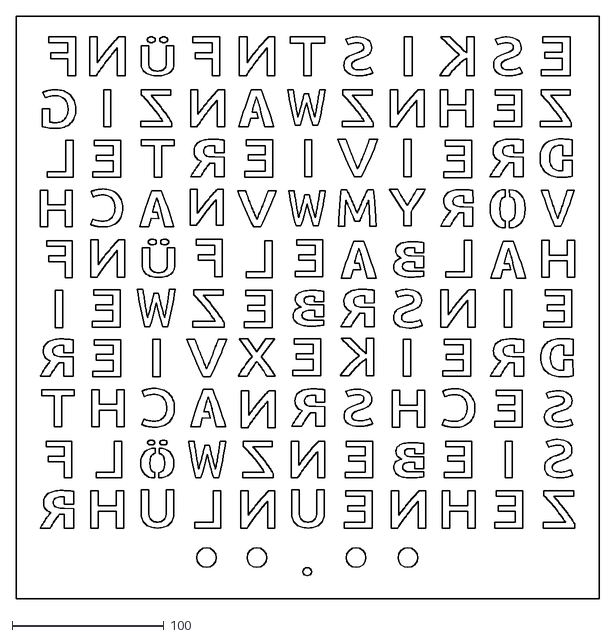
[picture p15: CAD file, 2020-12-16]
ZeichnungenBilder/ZeichnungFrontGross_SchuleFolie.dxf
384.2 x 384.2

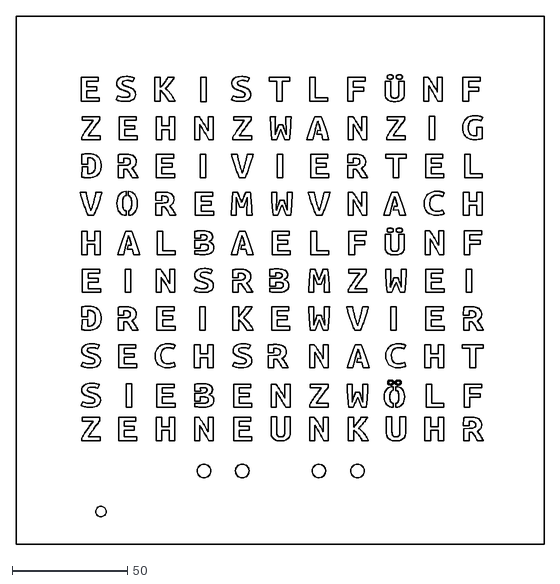
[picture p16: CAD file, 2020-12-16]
ZeichnungenBilder/Front_Ikea_Ribba_Laser.dxf
229.0 x 229.0

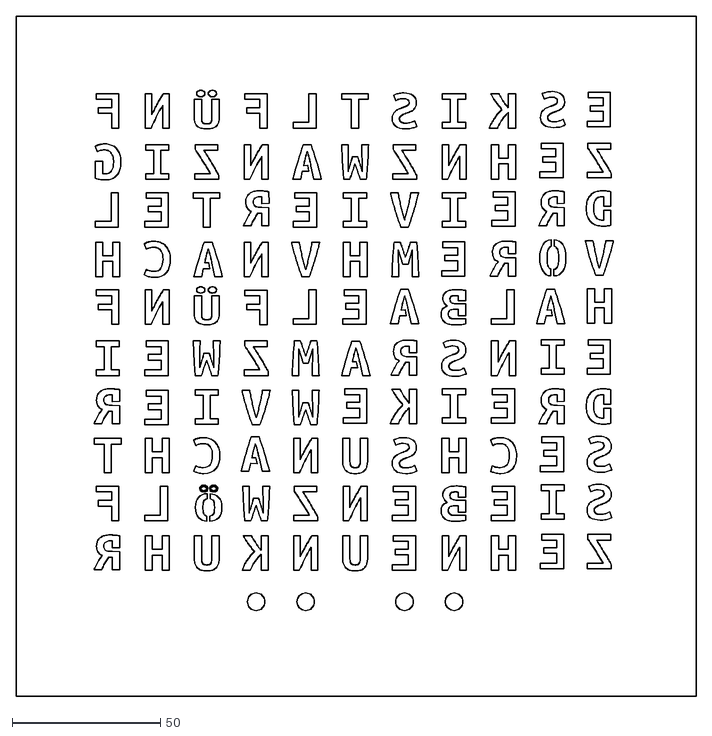
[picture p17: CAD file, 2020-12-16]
ZeichnungenBilder/Front_EntwurfFolie.dxf
229.0 x 229.0

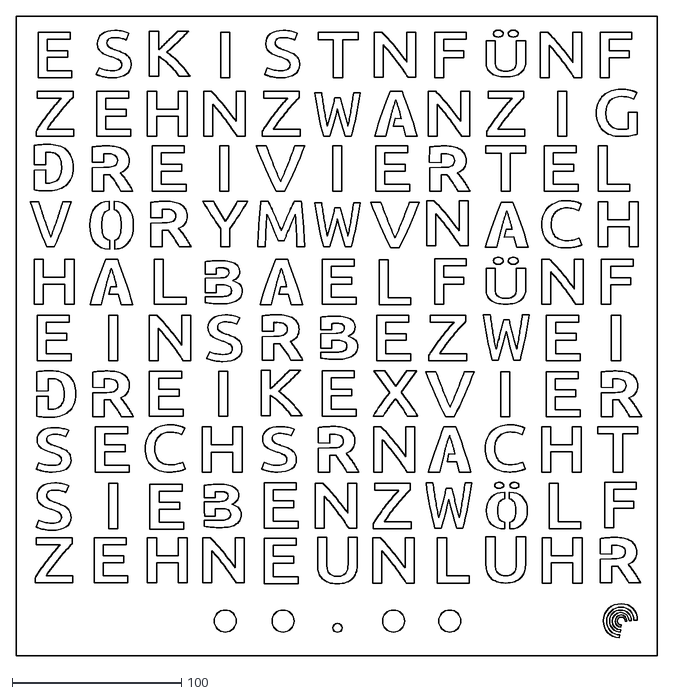
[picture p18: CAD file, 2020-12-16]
ZeichnungenBilder/ZeichnungFrontGross.dxf
379.1 x 377.9

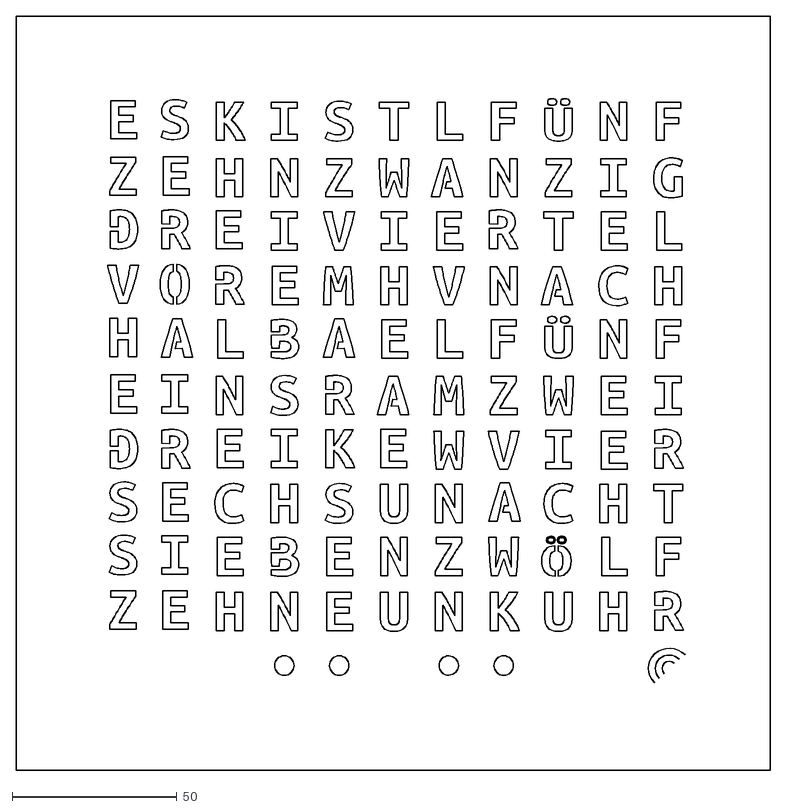
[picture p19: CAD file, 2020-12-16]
ZeichnungenBilder/Front_Entwurf.dxf
229.0 x 229.0

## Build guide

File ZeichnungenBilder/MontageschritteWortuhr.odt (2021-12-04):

Rahmenbau

- entferne den Sägegrat an vier Leisten mit dem Stechbeitel Vorsicht!! immer vom Körper weg arbeiten!!
- schneide an diesen vier Leisten, mit der Lehre, beide Seiten im 45° Winkel ab, spanne die Leisten ein, um ein verrutschen zu verhindern.
- Verleime die vier Leisten mit den Spannvorrichtungen, wische überschüssigen Leim ab!

Mindestens 60 Minuten warten!!

- entferne die Spannvorrichtungen
- schleife mit 120er Schleifpapier und dem Schleifblock die sichtbaren Seiten.
- bohre auf zwei gegenüberliegenden Seiten mittig ein Loch mit 4 mm und versenke das Bohrloch etwas, damit die Holzschraube eben abschließen kann.

Rückwand vorbereiten

- klebe auf die MDF-Platte (Mitteldichte Faserplatte) mit 38,2 cm mal 38,2 cm die beiden ausgeschnittenen Vorlagen passend auf
- bohre an den drei Markierungen 5 mm Löcher
- klebe die zwölf LED-Streifen in passender Länge und in der richtigen Pfeilrichtung auf
- schneide den grauen Rand von der mit LEDs bestückten Rückwand mit einem Cuttermesser ab und entferne den aufgeklebten grauen Rand

LED-Streifen verlöten

- verlöte mit Silberdraht alle LED-Streifen entsprechend der Vorlage
  - Achte darauf, dass sich die Drähte nicht berühren
  - zwischen den Lötstellen darf keine Brücke entstehen

Microcontroller und LDR verlöten

- am USB-Kabel die Kupplung abschneiden, ca. 4 cm abisolieren und alles außer das schwarze und rote Kabel abzwicken
- Kabel durch das unter Loch der Rückwand einfädeln und mit dem LED Streifen verlöten (rot +5V, schwarz GND)
- das USB-Kabel mit einem Kabelbinder vor dem Herausrutschen sichern
- LDR durch das kleine Brettchen stecken und über den 220 Ohm Widerstand mit GND verlöten
- zwischen Widerstand und LDR ein blaues Kabel anlöten
- am anderen Anschluss des LDR ein gelbes Kabel anlöten
- die Stromversorgung am Microcontroller über den ersten LED-Streifen verlöten (rot +5V, schwarz GND)
- die Datenleitung DIN des LED-Streifens mit PIN D8 und grünem Kabel verlöten
- das blaue Kabel vom LDR mit A0 verbinden
- das gelbe Kabel vom LDR mit 3,3 V verbinden

Rückwandrahmen verleimen, Lichtgitter zusammenbauen

- stecke das Lichtgitter aus 20 vorgesägten Leisten vorsichtig zusammen
- säge unten links am Lichtgitter 3 Felder ab
- lege das Lichtgitter auf die Rückwand und richte es aus
- klebe die zwei kurzen und zwei langen Seitenleisten auf die Rückwand um das Lichtgitter und verspanne alles Achte darauf, dass die Seitenleisten genau mit dem Rand der Rückwand abschließen!!
- das Brettchen mit dem LDR am Rahmen so verkleben, dass der LDR nicht über das Lichtgitter hinausragt!

Mindestens 60 Minuten warten!!

- Verspannungen entfernen und eventuell überstehende Leimreste entfernen

Funtionstest

- überprüfe alle Lötstellen mit der Lupe auf eventuelle Fehler
- stimmen alle Kabelverbindungen
- schließe das Netzteil am USB-Kabel an (auf der Uhr sollte in weiß WIFI zu erkennen sein
- verbinde dich per WIFI mit der Uhr (Anleitung)
- Teste alle Funktionen

Endmontage

- entferne alle Buchstaben aus dem Schnittmuster
- verklebe das Lichtgitter mit den Rahmenleisten der Rückwand
- beklebe das Lichtgitter mit Transparentpapier
- schneide das Feld über dem LDR frei
- lege das Schnittmuster auf das Lichtgitter und achte darauf, dass alle Buchstaben ohne Schatten erscheinen und der LDR, durch das mittlere Loch unten, sichtbar ist
- entferne vom Acrylglas die Schutzfolien und lege die Platte auf die Uhr
- schiebe den Rahmen so über die Uhr, dass die beiden Bohrungen seitlich liegen
- schraube den Rahmen zu

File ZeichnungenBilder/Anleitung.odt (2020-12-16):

Anleitung Wortuhr

# Ersteinrichtung

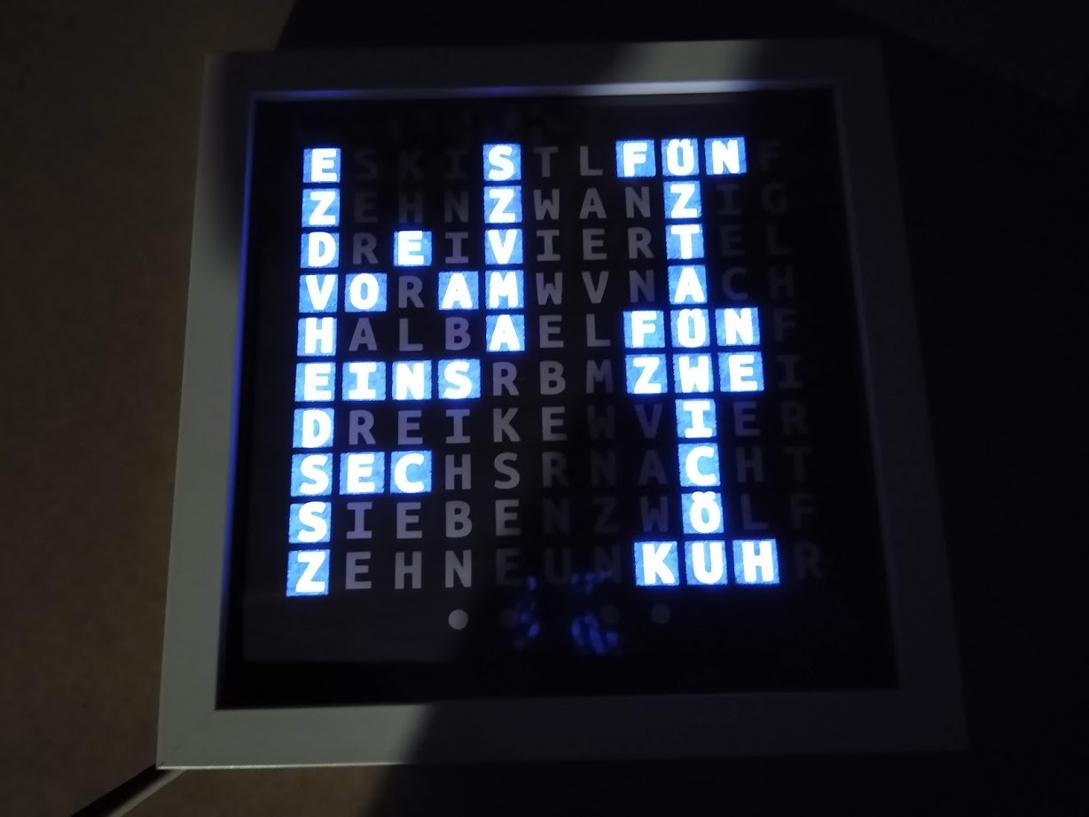
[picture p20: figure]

Wortuhr einschalten, auf der Uhr sollte WIFI in weiß erscheinen:

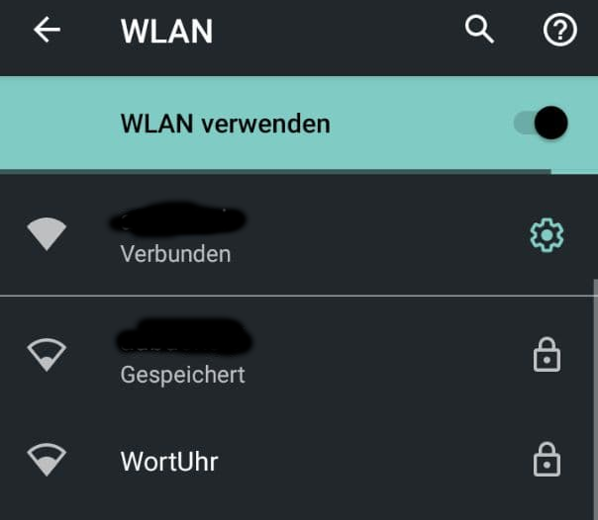
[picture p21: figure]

Jetzt sich mit einem Smartphone, Tablet oder Notebook in das WLAN der Wortuhr einloggen:

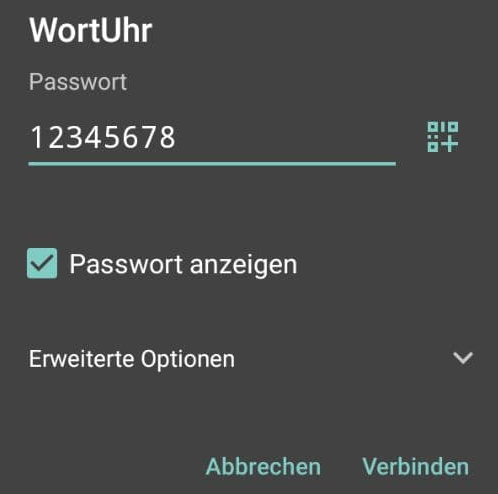
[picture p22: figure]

das Passwort "12345678" eingeben:

warten bis die Verbindung aufgebaut ist (Häkchen), die Meldung kein Internet kann hier ignoriert werden.

Sich mit dem Netzwerk "WortUhr.." durch anklicken verbinden, es sollte sich folgende Seite öffnen:

(öffnet sich die Seite nicht automatisch, dann in einem Browser die 192.168.4.1 in der Adresszeile eingeben.)

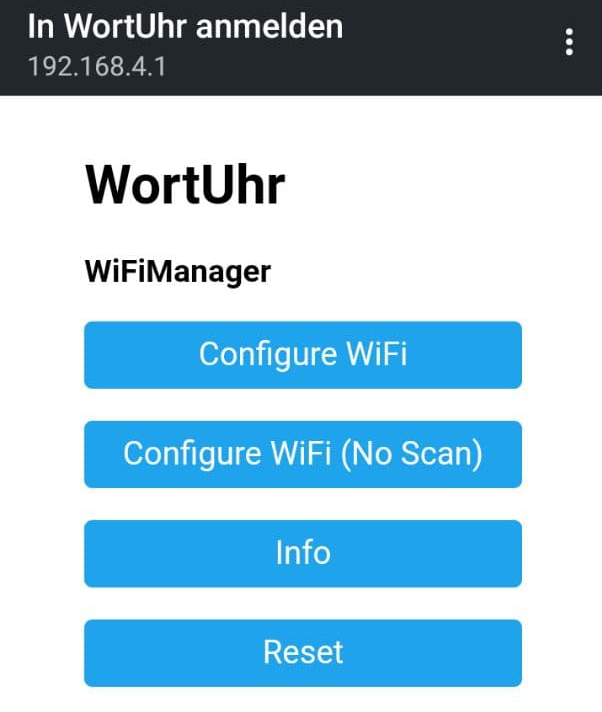
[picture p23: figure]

Configure WiFi auswählen

Sollte das heimische WLAN keine Kennung (SSID) verwenden, bitte Configure WiFi (No Scan) auswählen.

Das passende WLAN auswählen, das entsprechende Passwort eingeben und "save" drücken.

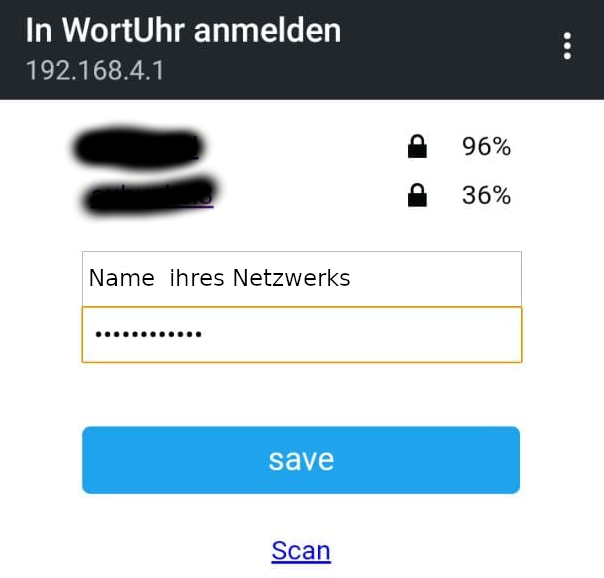
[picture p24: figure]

Nach kurzer Zeit zeigt die Uhr durch ein grünes WIFI in der Anzeige, dass die Verbindung aufgebaut ist.

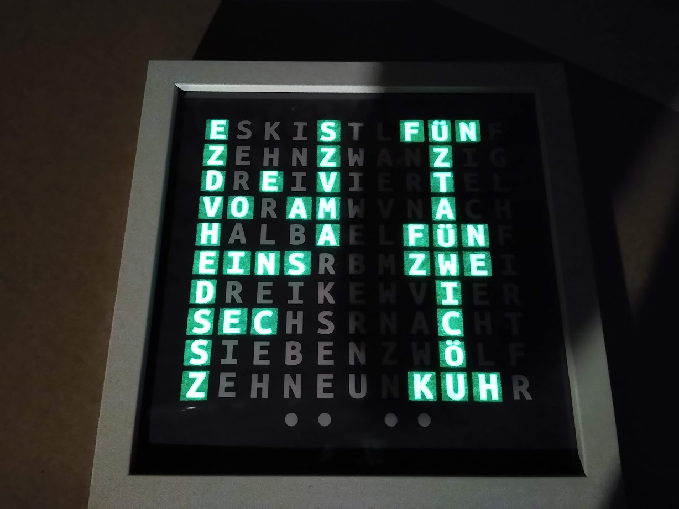
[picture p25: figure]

nun erscheint in Laufschrift die IP-Adresse der Uhr, bitte merken oder notieren.

# Grundlegende Einstellungen der Uhr

Sollten Sie Teil 1 der Anleitung (Ersteinrichtung) geschafft haben, zeigt die Uhr nach einigen Sekunden die richtige Uhrzeit schon an. Nach jedem Einschalten wird der WiFi-Verbindungsstatus durch das von weiß auf grün wechselnde WIFI auf der Uhr angezeigt und die aktuelle IP-Adresse in Laufschrift angegeben. (Bei eingebautem LDR kann die Laufschrift sehr dunkel und kaum zu erkennen sein, dann einfach kurz den LDR mit dem Finger abdunkeln, die Laufschrift sollte dann wieder heller werden)

Durch Eingabe dieser IP-Adresse in einen beliebigen Browser ihres Smartphones (Firefox, Chrom, Safari .....) können weitere Einstellungen an der Uhr vorgenommen werden:

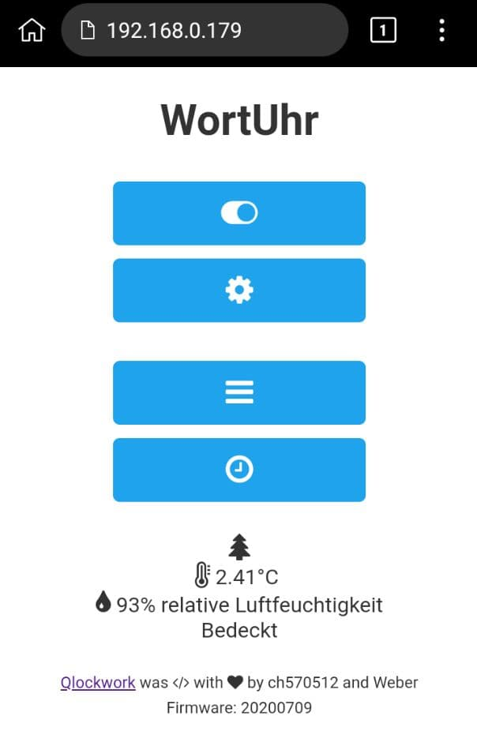
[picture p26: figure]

Diese Schaltfläche schaltet die Anzeige der Uhr aus, bzw. ein

hier können Einstellungen der Uhr verändert werden (siehe nächste Seite)

diese Schaltfläche wechselt durch die einzelnen Modi der Uhr (AM/PM, Sekunden, Wochentag, Datum, Mondphase, Außentemperatur, Luftfeuchtigkeit, mehrere Testmodi)

hier gelangt man immer wieder zurück zur Uhrzeit

### Helligkeitsregelung

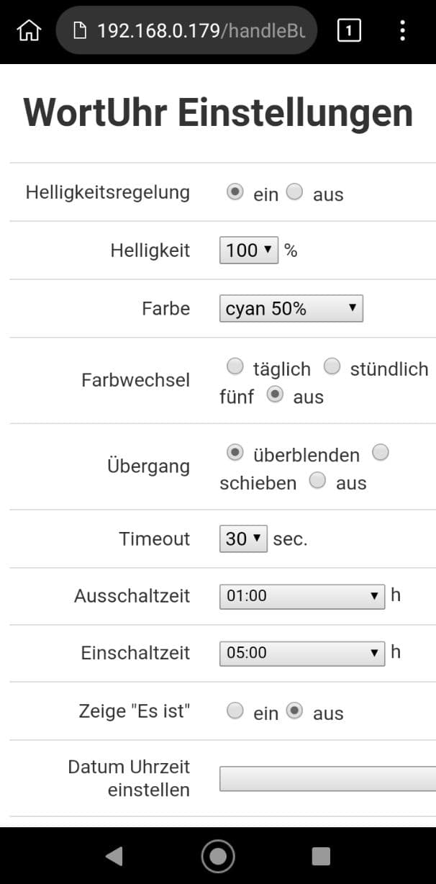
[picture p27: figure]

ein: die Helligkeitssteuerung übernimmt der LDR, d.h. je heller die Umgebung, desto heller erscheint die Uhr und je dunkler .....

aus: die Uhr leuchtet mit gleichbleibender, im nächsten Punkt einstellbarer, Helligkeit

### Helligkeit:

Ist die Helligkeitsregelung ein -> Einstellung der maximalen Helligkeit

Ist die Helligkeitsregelung aus -> Helligkeit der Uhr

### Farbe:

manuelle Farbwahl

### Farbwechsel:

täglich: jeden Tag wechselt die Farbe

stündlich: stündlich wechselt die Farbe

fünf: alle fünf Minuten wechselt die Farbe

aus: die unter Farbe eingestellte Farbe bleibt dauerhaft.

### Übergang: Übergangseffekte

überblenden: langsames Überblenden

schieben: Einfliegen von unten

aus: kein Übergangseffekt

### Timeout:

nach der eingestellten Zeit wechselt die Uhr von einem gewählten Modus zurück zur Uhrzeit.

### Ausschaltzeit:

Uhrzeit, bei der die Anzeige der Uhr aus geht

### Einschaltzeit:

Uhrzeit, bei der die Anzeige der Uhr wieder einschaltet

### Zeige „Es ist“:

die Anzeige "ES IST" ein- oder ausschalten (bei vollen und halben Stunden ist "ES IST" immer eingeblendet).

Datum Uhrzeit einstellen: manuelles Stellen der Uhr (sollte eigentlich nicht nötig sein, die Uhr bezieht die Uhrzeit aus dem Internet, also auch Sommer- oder Winterzeitumstellung erfolgt automatisch)

Alle Änderungen werden erst wirksam durch das Speichern (Häkchen ganz unten anklicken).

Damit man sich die IP-Adresse nicht immer merken muss und der Zugriff auf die Einstellungen schneller geht, kann eine Verknüpfung auf den Home-Screen des Smartphones oder Tablets erstellt werden:

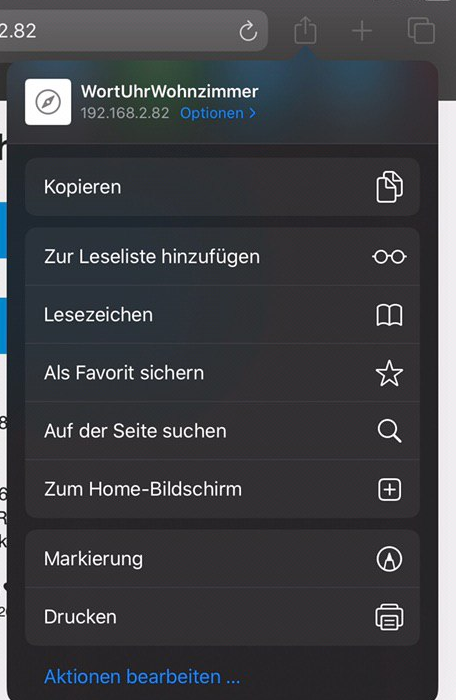
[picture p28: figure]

Android: Browser öffnen und IP-Adresse eingeben, nachdem die Startseite der Wortuhr geladen ist auf die drei Punkte oben rechts klicken und "Zum Startbildschirm hinzufügen" auswählen, der Wortuhr ggf. einen anderen Namen geben und hinzufügen anklicken, den weiteren Anweisungen folgen.

Apple: Safari öffnen und die IP-Adresse eingeben, nachdem die Startseite der Wortuhr geladen ist drücken sie den Teilen-Button und suchen den Menüpunkt "zum Home-Bildschirm" (sollte dieser Menüpunkt nicht sichtbarsein, einfach nach oben scrollen), ggf. einen anderen Namen geben und hinzufügen anklicken.

# Erweiterungen:

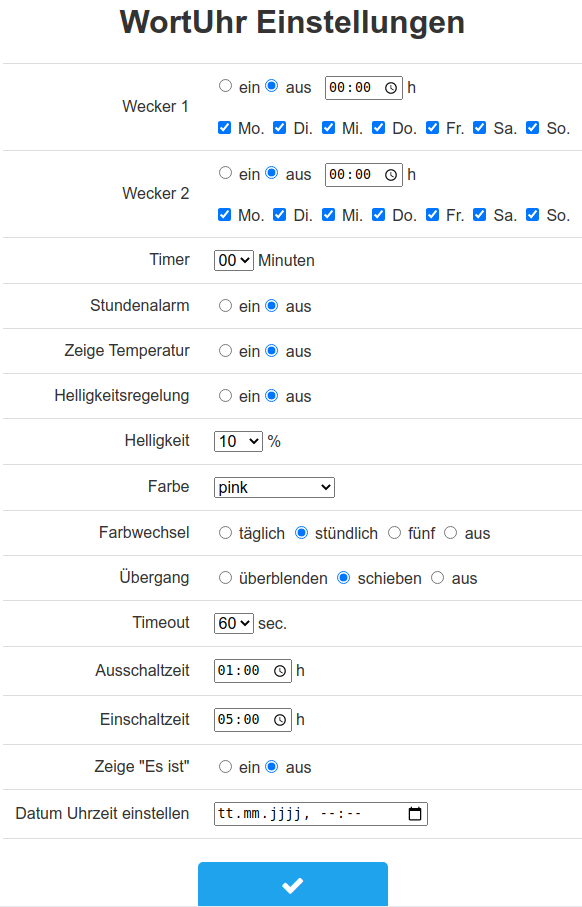
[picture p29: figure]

Ist ein Buzzer (Summer) oder ein RTC (RealTimeClock) eingebaut so ergeben sich weitere Einstellungsmöglichkeiten:

### Wecker 1 und 2:

Einstellungen für den Alarm, die Uhr piept dann im Sekundentakt für 30 Sekunden.

### Timer:

Nach Ablauf der eingestellten Zeit piept die Uhr für 30 Sekunden

### Stundenalarm:

Jede Stunde piept die Uhr einmal

### Zeige Temperatur:

bei jedem Zeitwechsel wird kurz die Innentemperatur angezeigt (nur bei eingebautem RTC)

# Spezialeinstellungen

Durch Eingaben in die Adresszeile des Browsers lassen sich Textnachrichten mit maximal 80 Zeichen oder an bestimmten Tagen Nachrichten auf der Anzeige der Uhr als Lauftext anzeigen.

### Events

Um an einem bestimmten Datum eine Nachricht alle 5 Minuten abzuspielen muss beispielsweise folgende Eingabe in der Adresszeile des Browsers eingegeben werden:

http://IP-Adresse_ihrer_Wortuhr/setEvent?day=1&month=5&color=5&text=Erster Mai! Tag der Arbeit

IP-Adresse_ihrer_Wortuhr:

die beim Einschalten angezeigte IP-Adresse in der Form xxx.xxx.xxx.xxx

day=Tag

month=Monat

color=0-24 (0=weiß, 1= rot, ..... 24=pink, Reihenfolge wie in den oben beschriebenen Einstellungen)

text=Anzuzeigender Text (bitte keine Umlaute)

Um einen Eventeintrag wieder zu löschen, kann einfach ein Event ohne Textinhalt zum gleichen Datum eingegeben werden, denn pro Tag ist nur ein Eventeintrag möglich. Also in unserem Beispiel:

http://IP-Adresse_ihrer_Wortuhr/setEvent?day=1&month=5&color=5&text=

### Lauftexte

Um sofort eine Textnachricht auf der Uhr anzuzeigen kann folgende Befehlszeile in die Adresszeile des Browsers eingegeben werden

http://IP-Adresse_ihrer_Wortuhr/showText?buzzer=2&color=0&text=Ihr Text

IP-Adresse_ihrer_Wortuhr:

die beim Einschalten angezeigte IP-Adresse in der Form xxx.xxx.xxx.xxx

buzzer=2 ein eventuell eingauter Buzzer piept 2 mal

color=0-24 (0=weiß, 1= rot, ..... 24=pink, Reihenfolge wie in den oben beschriebenen Einstellungen)

text=Anzuzeigender Text (bitte keine Umlaute)

### FAQ: freqently asked questions / häufig gestellte Fragen

Home-Screen-Link funktioniert nicht mehr

Wird die Uhr längere Zeit vom WLAN getrennt oder der Router neu gestartet (Stromausfall) erhält die Uhr ggf. eine andere IP-Adresse als zuvor und der Link auf dem Home-Screen (falls erstellt) verliert seine Gültigkeit. Will man dies vermeiden muss man der Uhr über ihre MAC-Adresse eine feste IP-Adresse zuweisen. Dies ist je nach eingesetztem Router unterschiedlich und sollte im Handbuch des Routers dokumentiert sein, folgende Schlagworte können bei der Suche hilfreich sein: DHCP, Adress Reservation, IP-Binding ...

Was tun bei Umzug oder Routerwechsel:

Sobald die Uhr ihr, in der Ersteinrichtung mitgeteiltes, Wlan nicht mehr findet (neuer Router oder veränderter Standort), wechselt Sie nach 120 Sekunden in den Einrichtungsmodus und kann, wie im Punkt Ersteinrichtung beschrieben, im neuen Wlan angemeldet werden.

Die Uhr zeigt immer zwölf Uhr an

Dies kann passieren, falls die Uhr kein Zeitsignal über das WLAN empfangen kann. Häufig behebt ein kurzes Ausstecken und erneutes Starten der Uhr dieses Problem. Sollte der Fehler weiterhin auftreten, sollte ein Standort mit besserem WLAN-Empfang gewählt werden.

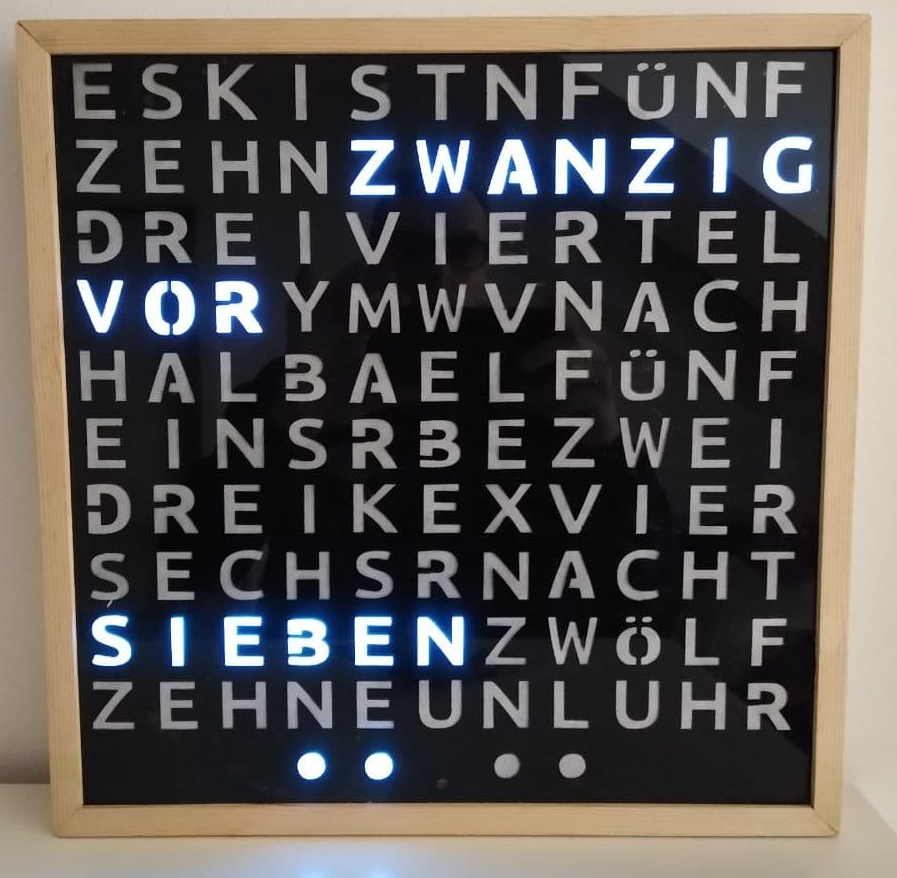
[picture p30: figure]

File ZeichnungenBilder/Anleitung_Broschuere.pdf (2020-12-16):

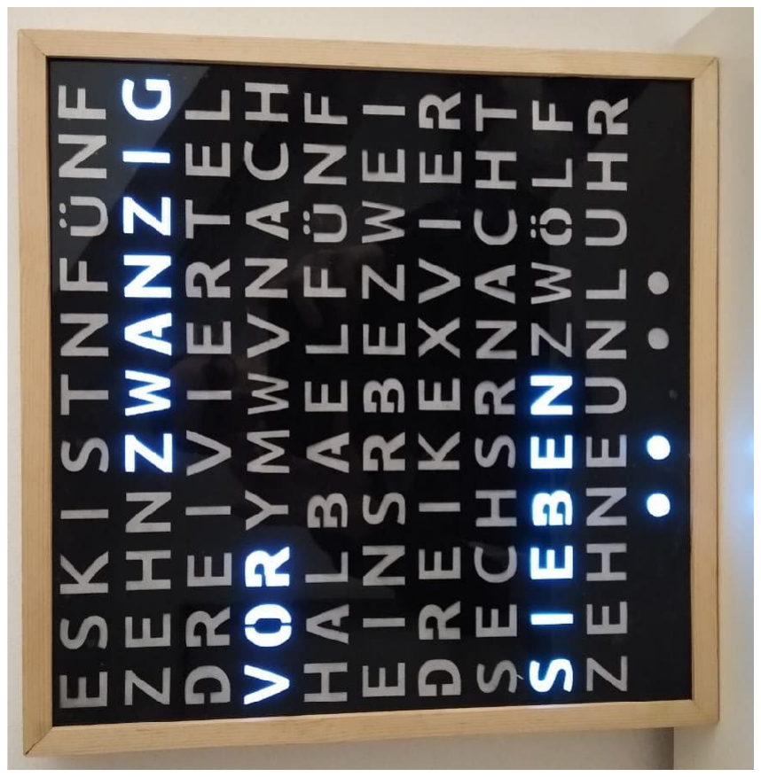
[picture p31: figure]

## Inhaltsverzeichnis

Ersteinrichtung | 1
Grundlegende Einstellungen der Uhr | 3

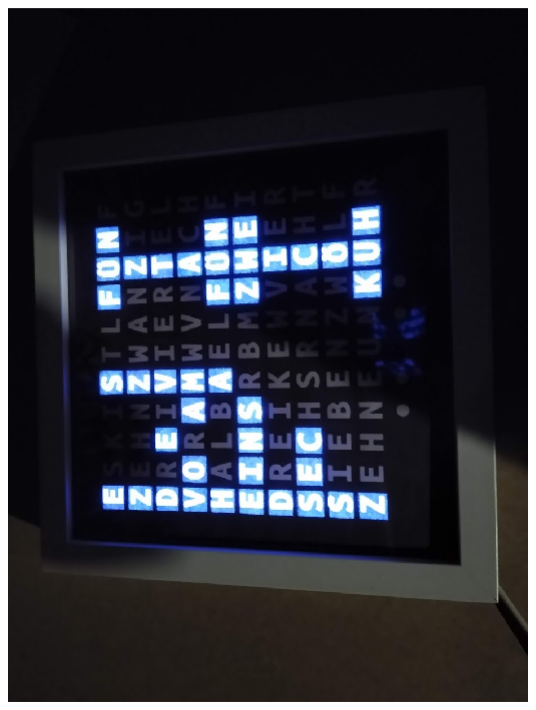
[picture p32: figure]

Helligkeitsregelung | 4
Helligkeit: | 4
Farbe: | 4
Farbwechsel: | 4
Übergang: Übergangseffekte | 4
Timeout: | 4
Ausschaltzeit: | 4
Einschaltzeit: | 4
Zeige „Es ist“: | 4
Erweiterungen: | 5
Wecker 1 und 2: | 5
Timer: | 5
Stundenalarm: | 5
Zeige Temperatur: | 5
Spezialeinstellungen | 6

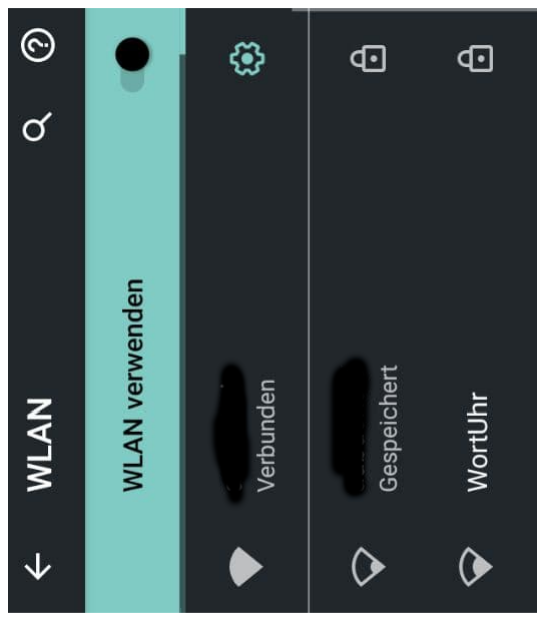
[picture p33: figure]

Events | 6
Lauftexte | 6
FAQ: freqently asked questions / häufig gestellte Fragen | 7
8

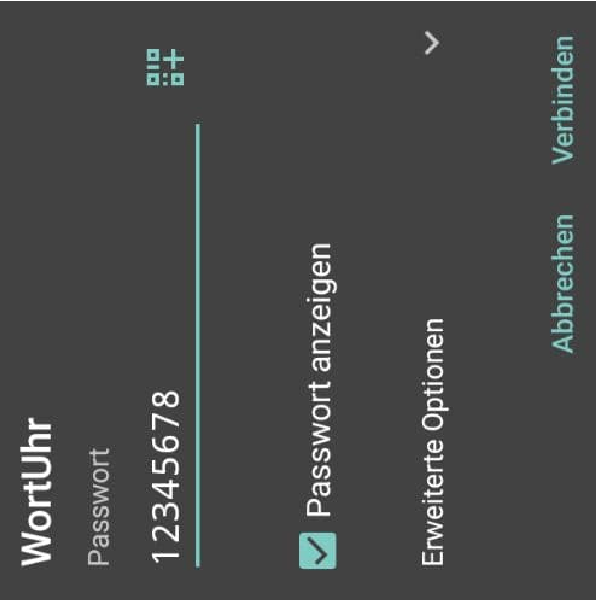
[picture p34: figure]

# Anleitung Wortuhr

# Ersteinrichtung

Wortuhr einschalten, auf der Uhr sollte

WIFI in weiß erscheinen:

Jetzt sich mit einem Smartphone, Tablet oder

Notebook in das WLAN der Wortuhr einloggen:

das Passwort "12345678" eingeben:

warten bis die Verbindung aufgebaut ist

(Häkchen), die Meldung kein Internet kann hier

ignoriert werden.

Sich mit dem Netzwerk "WortUhr.." durch

anklicken verbinden, es sollte sich folgende Seite

öffnen:

1

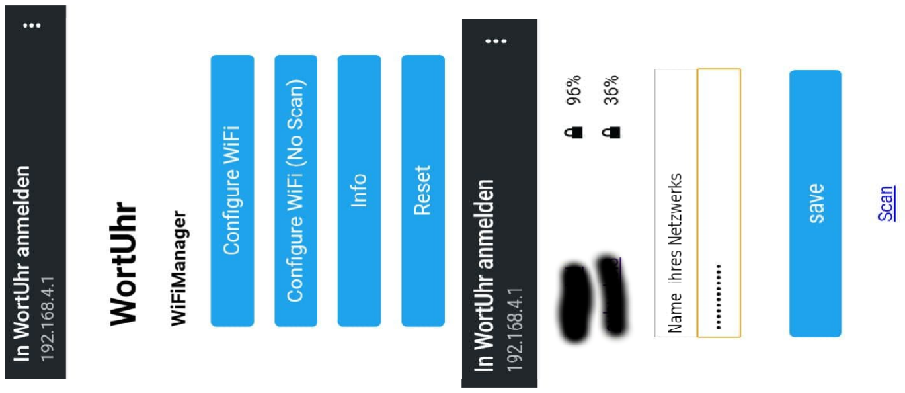
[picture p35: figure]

(öffnet sich die Seite nicht automatisch, dann in einem Browser die 192.168.4.1 in der Adresszeile

eingeben.)

Configure WiFi auswählen

Sollte das heimische WLAN keine Kennung (SSID)

verwenden, bitte Configure WiFi (No Scan) auswählen. Das passende WLAN auswählen, das entsprechende

Passwort eingeben und "save" drücken.

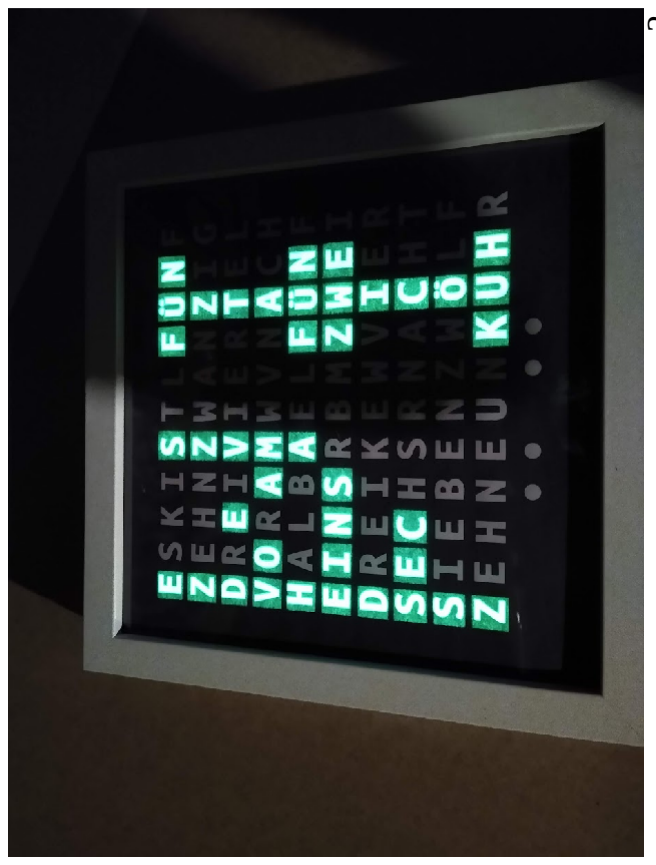
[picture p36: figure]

Nach kurzer Zeit zeigt die Uhr durch

ein grünes WIFI in der Anzeige, dass

die Verbindung aufgebaut ist.

nun erscheint in Laufschrift die IP-

Adresse der Uhr, bitte merken oder

notieren.

2

FAQ: freqently asked questions / häufig gestellte Fragen

Home-Screen-Link funktioniert nicht mehr

Wird die Uhr längere Zeit vom WLAN getrennt oder der Router neu gestartet (Stromausfall) erhält
die Uhr ggf. eine andere IP-Adresse als zuvor und der Link auf dem Home-Screen (falls erstellt)

verliert seine Gültigkeit. Will man dies vermeiden muss man der Uhr über ihre MAC-Adresse eine

feste IP-Adresse zuweisen. Dies ist je nach eingesetztem Router unterschiedlich und sollte im

Handbuch des Routers dokumentiert sein, folgende Schlagworte können bei der Suche hilfreich

sein: DHCP, Adress Reservation, IP-Binding ...
Was tun bei Umzug oder Routerwechsel:

Sobald die Uhr ihr, in der Ersteinrichtung mitgeteiltes, Wlan nicht mehr findet (neuer Router oder

veränderter Standort), wechselt Sie nach 120 Sekunden in den Einrichtungsmodus und kann, wie im

Punkt Ersteinrichtung beschrieben, im neuen Wlan angemeldet werden.

Die Uhr zeigt immer zwölf Uhr an

Dies kann passieren, falls die Uhr kein Zeitsignal über das WLAN empfangen kann. Häufig behebt
ein kurzes Ausstecken und erneutes Starten der Uhr dieses Problem. Sollte der Fehler weiterhin

auftreten, sollte ein Standort mit besserem WLAN-Empfang gewählt werden.

7

# Spezialeinstellungen

Durch Eingaben in die Adresszeile des Browsers lassen sich Textnachrichten mit maximal 80

Zeichen oder an bestimmten Tagen Nachrichten auf der Anzeige der Uhr als Lauftext anzeigen.

Events

Um an einem bestimmten Datum eine Nachricht alle 5 Minuten abzuspielen muss

beispielsweise folgende Eingabe in der Adresszeile des Browsers eingegeben werden:

http://IP-Adresse_ihrer_Wortuhr/setEvent?day=1&month=5&color=5&text=Erster Mai! Tag der

Arbeit

IP-Adresse_ihrer_Wortuhr:

die beim Einschalten angezeigte IP-Adresse in der Form xxx.xxx.xxx.xxx

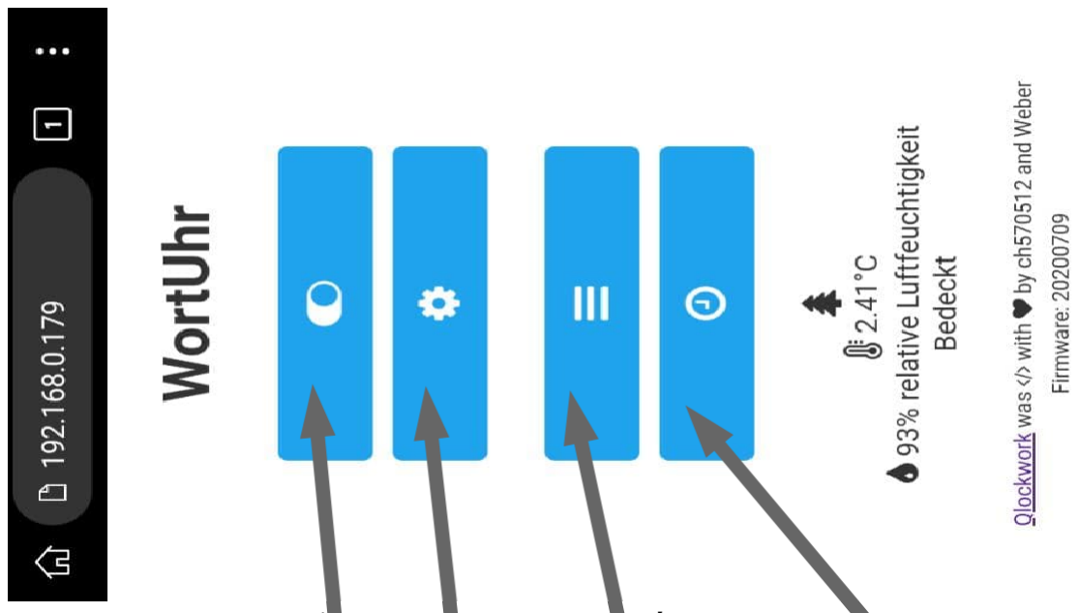
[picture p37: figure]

day=Tag

month=Monat

color=0-24 (0=weiß, 1= rot, ..... 24=pink, Reihenfolge wie in den oben beschriebenen

Einstellungen)

text=Anzuzeigender Text (bitte keine Umlaute)

Um einen Eventeintrag wieder zu löschen, kann einfach ein Event ohne Textinhalt zum gleichen

Datum eingegeben werden, denn pro Tag ist nur ein Eventeintrag möglich. Also in unserem

Beispiel:

http://IP-Adresse_ihrer_Wortuhr/setEvent?day=1&month=5&color=5&text=

Lauftexte

Um sofort eine Textnachricht auf der Uhr anzuzeigen kann folgende Befehlszeile in die

Adresszeile des Browsers eingegeben werden http://IP-Adresse_ihrer_Wortuhr/showText?buzzer=2&color=0&text=Ihr Text

IP-Adresse_ihrer_Wortuhr:

die beim Einschalten angezeigte IP-Adresse in der Form xxx.xxx.xxx.xxx

buzzer=2 ein eventuell eingauter Buzzer piept 2 mal

color=0-24 (0=weiß, 1= rot, ..... 24=pink, Reihenfolge wie in den oben beschriebenen

Einstellungen)

text=Anzuzeigender Text (bitte keine Umlaute)

6

# Grundlegende Einstellungen der Uhr

Sollten Sie Teil 1 der Anleitung (Ersteinrichtung) geschafft haben, zeigt die Uhr nach einigen

Sekunden die richtige Uhrzeit schon an. Nach jedem Einschalten wird der WiFi-Verbindungsstatus
durch das von weiß auf grün wechselnde WIFI auf der Uhr angezeigt und die aktuelle IP-Adresse
in Laufschrift angegeben. (Bei eingebautem LDR kann die Laufschrift sehr dunkel und kaum zu

erkennen sein, dann einfach kurz den LDR mit dem Finger abdunkeln, die Laufschrift sollte dann

wieder heller werden)

Durch Eingabe dieser IP-Adresse in einen beliebigen Browser ihres Smartphones (Firefox, Chrom,

Safari .....) können weitere Einstellungen an der Uhr vorgenommen werden:

Diese Schaltfläche schaltet die Anzeige der Uhr aus, bzw.

ein

hier können Einstellungen der Uhr verändert werden

(siehe nächste Seite)

diese Schaltfläche wechselt durch die einzelnen Modi der

Uhr (AM/PM, Sekunden, Wochentag, Datum,

Mondphase, Außentemperatur, Luftfeuchtigkeit, mehrere

Testmodi)

hier gelangt man immer wieder zurück zur Uhrzeit

3

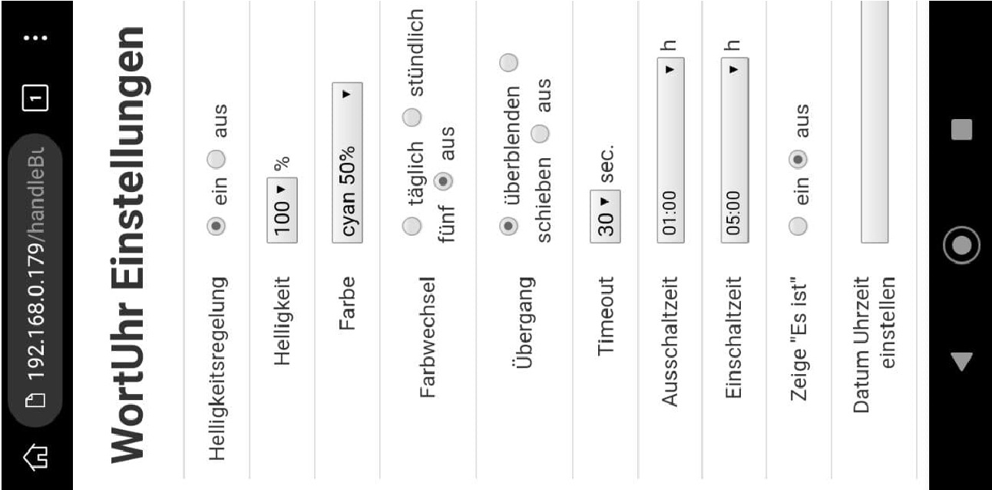
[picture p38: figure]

Helligkeitsregelung

ein: die Helligkeitssteuerung übernimmt der LDR,
d.h. je heller die Umgebung, desto heller erscheint

die Uhr und je dunkler .....

aus: die Uhr leuchtet mit gleichbleibender, im

nächsten Punkt einstellbarer, Helligkeit

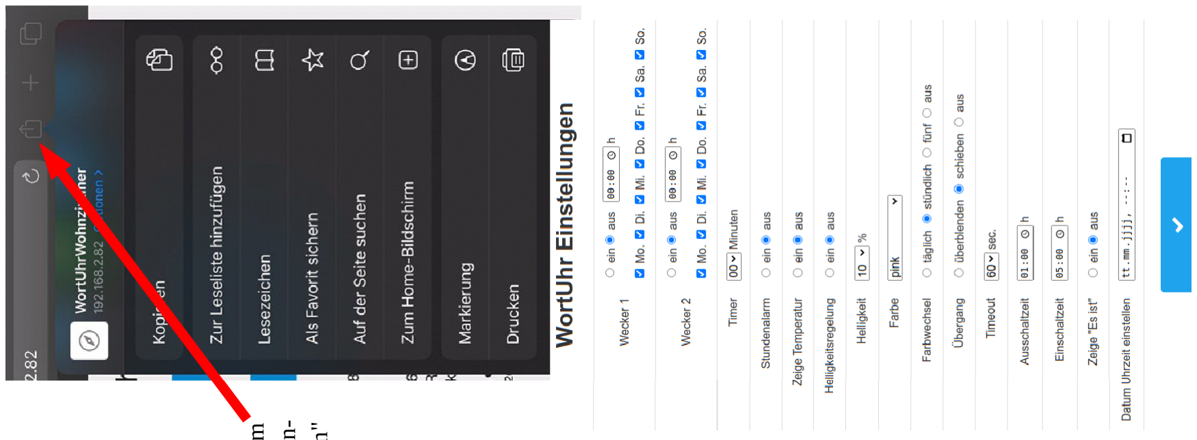
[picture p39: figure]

Helligkeit:

Ist die Helligkeitsregelung ein -> Einstellung der

maximalen Helligkeit

Ist die Helligkeitsregelung aus -> Helligkeit der Uhr

Farbe:

manuelle Farbwahl
Farbwechsel:

täglich: jeden Tag wechselt die Farbe

stündlich: stündlich wechselt die Farbe

fünf: alle fünf Minuten wechselt die Farbe

aus: die unter Farbe eingestellte Farbe bleibt

dauerhaft.

Übergang: Übergangseffekte

überblenden: langsames Überblenden

schieben: Einfliegen von unten

aus: kein Übergangseffekt

Timeout:

nach der eingestellten Zeit wechselt die Uhr von einem gewählten Modus zurück zur Uhrzeit.

Ausschaltzeit:

Uhrzeit, bei der die Anzeige der Uhr aus geht

Einschaltzeit:

Uhrzeit, bei der die Anzeige der Uhr wieder einschaltet

Zeige „Es ist“:

die Anzeige "ES IST" ein- oder ausschalten (bei vollen und halben Stunden ist "ES IST" immer

eingeblendet).

4

Datum Uhrzeit einstellen: manuelles Stellen der Uhr (sollte eigentlich nicht nötig sein, die Uhr

bezieht die Uhrzeit aus dem Internet, also auch Sommer- oder Winterzeitumstellung erfolgt

automatisch)

Alle Änderungen werden erst wirksam durch das Speichern (Häkchen ganz unten anklicken).

Damit man sich die IP-Adresse nicht immer merken muss und der Zugriff auf die Einstellungen

schneller geht, kann eine Verknüpfung auf den Home-Screen des Smartphones oder Tablets erstellt

werden:

Android: Browser öffnen und IP-Adresse eingeben,

nachdem die Startseite der Wortuhr geladen ist auf die drei

Punkte oben rechts klicken und "Zum Startbildschirm

hinzufügen" auswählen, der Wortuhr ggf. einen anderen
Namen geben und hinzufügen anklicken, den weiteren

Anweisungen folgen.

Apple: Safari öffnen und die IP-Adresse eingeben, nachdem

die Startseite der Wortuhr geladen ist drücken sie den Teilen-Button und suchen den Menüpunkt "zum Home-Bildschirm"
(sollte dieser Menüpunkt nicht sichtbarsein, einfach nach
oben scrollen), ggf. einen anderen Namen geben und

hinzufügen anklicken.

# Erweiterungen:

Ist ein Buzzer (Summer) oder ein RTC (RealTimeClock)

eingebaut so ergeben sich weitere

Einstellungsmöglichkeiten:

Wecker 1 und 2:

Einstellungen für den Alarm, die Uhr piept dann im

Sekundentakt für 30 Sekunden.

Timer:

Nach Ablauf der eingestellten Zeit piept die Uhr für 30

Sekunden

Stundenalarm:

Jede Stunde piept die Uhr einmal

Zeige Temperatur:

bei jedem Zeitwechsel wird kurz die Innentemperatur

angezeigt (nur bei eingebautem RTC)

5

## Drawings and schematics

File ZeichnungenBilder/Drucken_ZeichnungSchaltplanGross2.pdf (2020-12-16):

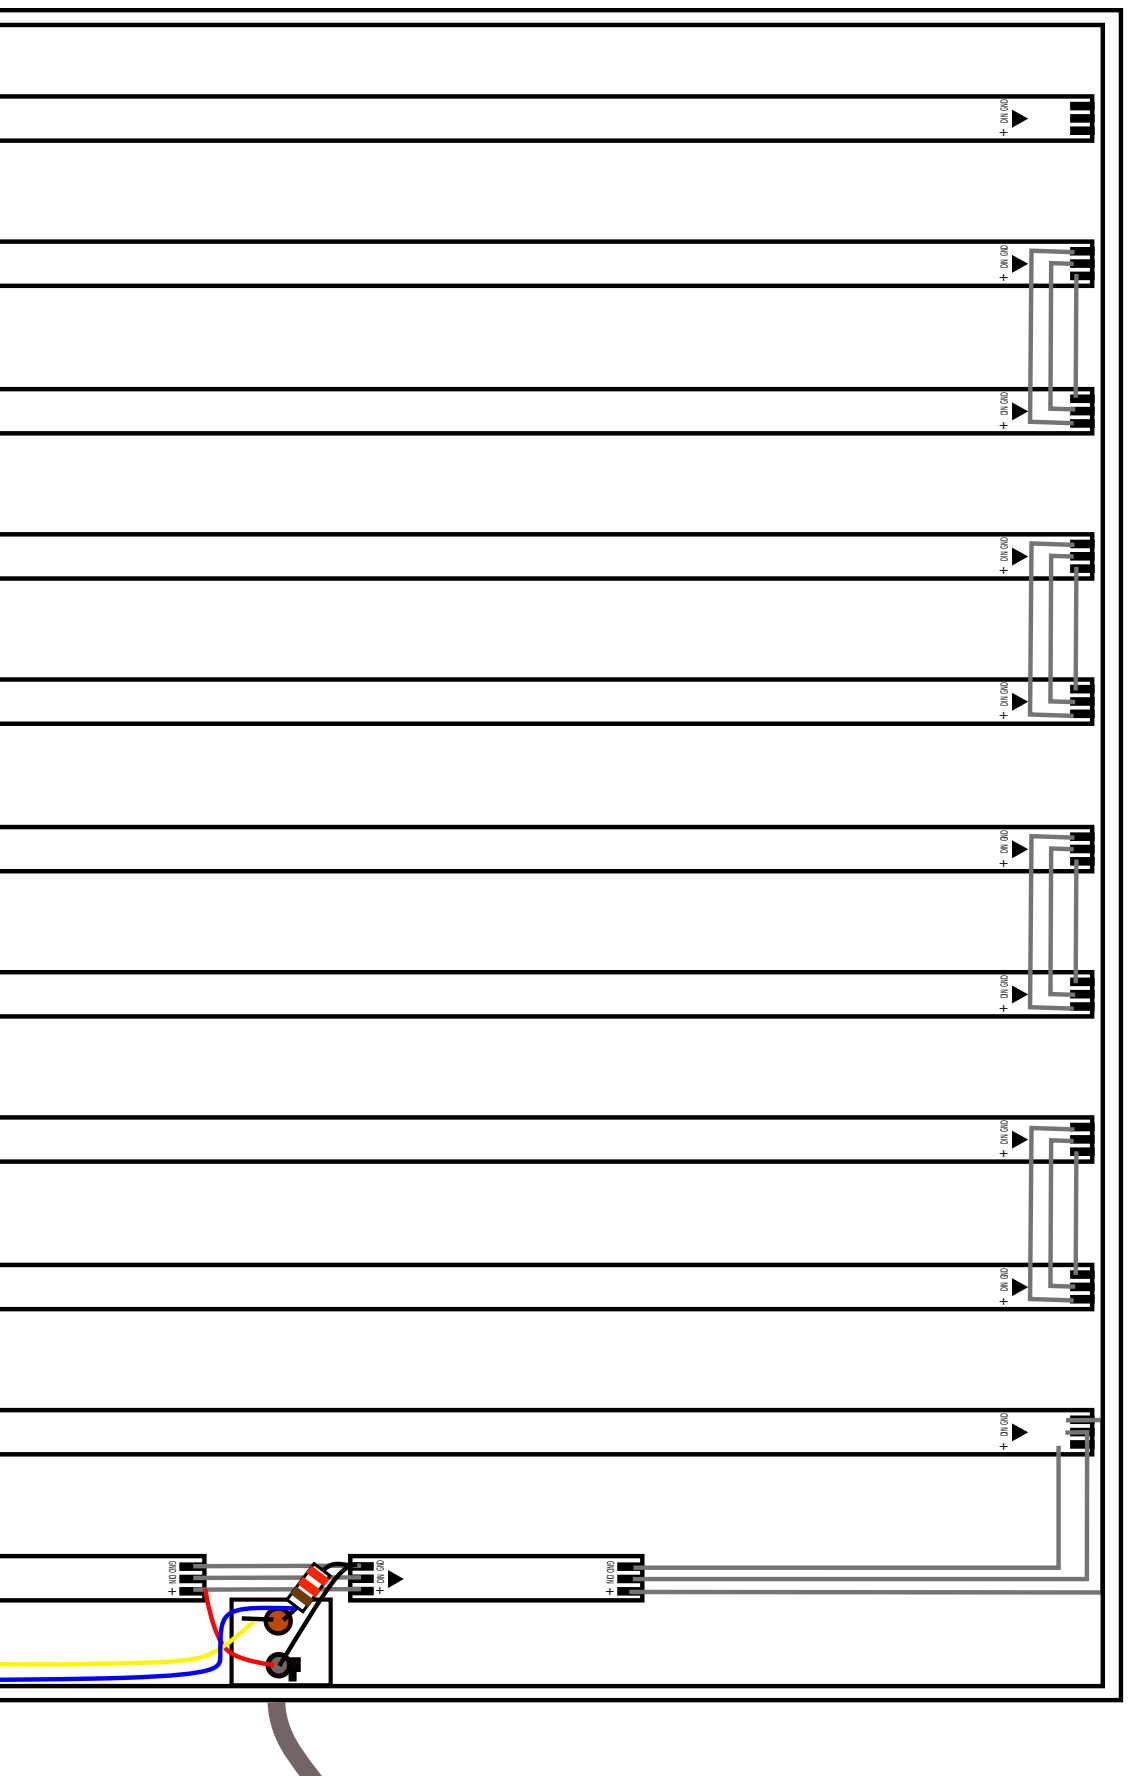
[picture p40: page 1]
+GND DIN

+GND DIN +GND DIN +GND DIN +GND DIN +GND DIN

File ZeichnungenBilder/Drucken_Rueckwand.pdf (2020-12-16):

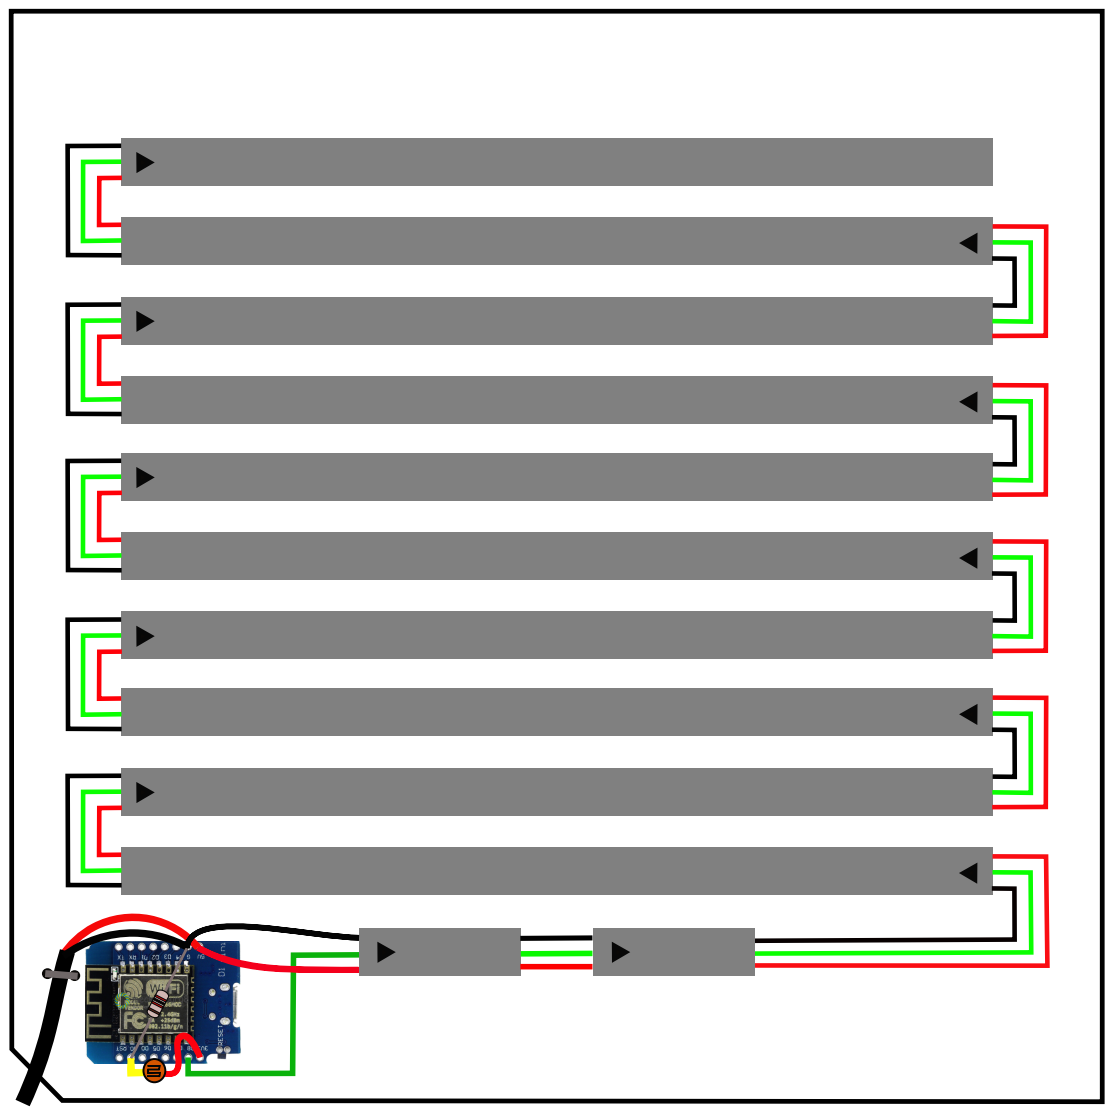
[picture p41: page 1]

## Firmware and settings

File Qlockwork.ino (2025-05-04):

//*****************************************************************************
// zytQuadrat
// An advanced firmware for a DIY "word-clock"
//
// @mc ESP8266
// @created 12.03.2017
//
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
//*****************************************************************************

#define FIRMWARE_VERSION 20241114

#include <Arduino.h>
#include <Arduino_JSON.h>
#include <ArduinoHttpClient.h>
#include <ArduinoOTA.h>

#include <ESP8266HTTPUpdateServer.h>
#include <ESP8266mDNS.h>
#include <ESP8266WebServer.h>
#include <ESP8266WiFi.h>
#include <WiFiManager.h>
#include <TimeLib.h>
#include <LittleFS.h>

#include "Colors.h"
#include "Configuration.h"
#include "Event.h"
#include "LedDriver.h"
#include "Modes.h"
#include "Ntp.h"
#include "OpenWeather.h"
#include "Renderer.h"
#include "Settings.h"
#include "Syslog.h"
#include "Timezone.h"
#include "Timezones.h"
#include "Animation.h"
#include "html_content.h"

#ifdef IR_RECEIVER
#include <IRremoteESP8266.h>
#include <IRrecv.h>
#include <IRutils.h>
#endif

#ifdef RTC_BACKUP
#include <DS3232RTC.h>
#endif

#ifdef SENSOR_DHT22
#include <DHT.h>
#endif

#ifdef SENSOR_BME280
#include <Adafruit_BME280.h>
#endif

#ifdef SENSOR_MCP9808
#include <Adafruit_MCP9808.h>
#endif

#define MILLIS_2_HZ 500

//*****************************************************************************
// Init
//*****************************************************************************
char HostName[32];
char HostNameAp[32];

// Servers
ESP8266WebServer webServer(80);
ESP8266HTTPUpdateServer httpUpdater;

// DHT22
#ifdef SENSOR_DHT22
DHT dht(PIN_DHT22, DHT22);
#endif

// BME280
#ifdef SENSOR_BME280
Adafruit_BME280 bme;
#endif

// MCP9808
#ifdef SENSOR_MCP9808
Adafruit_MCP9808 mcp;
#endif

// IR receiver
#ifdef IR_RECEIVER
IRrecv irrecv(PIN_IR_RECEIVER);
decode_results irDecodeResult;
unsigned long last_ir_millis = 0;
#endif

// Syslog
#ifdef SYSLOGSERVER_SERVER
WiFiUDP wifiUdp;
Syslog syslog(wifiUdp, SYSLOGSERVER_SERVER, SYSLOGSERVER_PORT, HostName, "zytQuadrat", LOG_INFO);
#endif

// RTC
#ifdef RTC_BACKUP
DS3232RTC RTC;
#endif

// LED driver 
LedDriver ledDriver;

// Renderer
Renderer renderer;

// Settings
Settings settings;

// NTP
Ntp ntp;
char ntpServer[] = NTP_DEFAULT_SERVER;
uint8_t errorCounterNTP = 0;

// Screenbuffer
uint16_t matrix[NUMPIXELS_Y] = {};
uint16_t matrixOld[NUMPIXELS_Y] = {};
bool screenBufferNeedsUpdate = true;
bool colorNeedsChange = false;
uint8_t colorOld;

// Mode
Mode mode = MODE_TIME;
Mode lastMode = mode;
uint32_t modeTimeout = 0;
uint32_t autoModeChangeTimer = AUTO_MODECHANGE_TIME;
bool runTransitionOnce = false;
bool runTransitionDemo = false;
uint8_t autoMode = 0;

// Time
uint8_t lastDay = 0;
uint8_t lastMinute = 0;
uint8_t lastHour = 0;
uint8_t lastSecond = 0;
time_t upTime = 0;
uint8_t randomHour = 0;
uint8_t randomMinute = 0;
uint8_t randomSecond = 0;
uint8_t moonphase = 0;

// Feed
String feedText = "";
uint8_t feedColor = WHITE;
uint8_t feedPosition = 0;

// OpenWeather
#ifdef APIKEY
OpenWeather outdoorWeather;
uint8_t errorCounterOutdoorWeather = 0;
#endif

// Temperature Sensor
float roomTemperature = 0;
uint8_t errorCounterMCP = 0;

// Humidity Sensor
float roomHumidity = 0;
uint8_t errorCounterDHT = 0;
uint8_t errorCounterBME = 0;

// Brightness and LDR
uint8_t maxBrightness = map(settings.mySettings.brightness, 0, 100, MIN_BRIGHTNESS, MAX_BRIGHTNESS);
uint8_t brightness = maxBrightness;
#ifdef LDR
uint16_t ldrValue = 0;
uint16_t lastLdrValue = 0;
uint16_t minLdrValue = LDR_MIN_DEFAULT;
uint16_t maxLdrValue = LDR_MAX_DEFAULT;
#endif

// Alarm
#ifdef BUZZER
bool alarmTimerSet = false;
uint8_t alarmTimer = 0;
uint8_t alarmTimerSecond = 0;
uint8_t alarmOn = false;
#endif

// Events
#if defined(SHOW_MODE_SUNRISE_SUNSET) && defined(APIKEY)
bool sunrise_started = false;
unsigned long sunrise_millis = 0;
bool sunset_started = false;
unsigned long sunset_millis = 0;
time_t sunset_unix = 0;
time_t sunrise_unix = 0;
int save_color_sunrise_sunset = 0;
#endif

// Misc
uint8_t testColumn = 0;
int updateInfo = 0;
IPAddress myIP = { 0,0,0,0 };
uint32_t lastButtonPress = 0;
uint32_t lastModePress = 0;
uint8_t modeButtonStage = 0;
bool testFlag = false;
unsigned long mood_millis = 0;
uint32_t lastMillis2Hz = 0;

uint32_t connectMillis = 0;
bool connecting = false;
bool startWps = false;

//Animationen
s_myanimation myanimation;
s_frame copyframe;
uint32_t anipalette[] = { 0xFF0000, 0xFFAA00, 0xFFFF00, 0x00FF00, 0x00FFFF, 0x0000FF, 0xAA00FF, 0xFF00FF, 0x000000, 0xFFFFFF };
String myanimationslist[MAXANIMATION];
uint8_t akt_aniframe = 0;
uint8_t akt_aniloop = 0;
uint8_t frame_fak = 1;        // Animationsrichtung
String animation;
bool playanimation = false;

uint16_t minFreeBlockSize = 10000;
uint16_t codeline = 0;
String codetab;

struct rst_info *rtc_info;

WiFiEventHandler wifiConnectHandler;
WiFiEventHandler wifiDisconnectHandler;

void onWifiConnect(const WiFiEventStationModeGotIP& event) {
  Serial.println("Connected to Wi-Fi sucessfully.");
  Serial.print("IP address: ");
  Serial.println(WiFi.localIP());
}

void onWifiDisconnect(const WiFiEventStationModeDisconnected& event) {
  Serial.println("Disconnected from Wi-Fi.");
}

//*****************************************************************************
// Setup()
//*****************************************************************************

void setup()
{
    // init serial port
    Serial.begin(SERIAL_SPEED);
    while (!Serial);
    delay(1000);

    rtc_info = system_get_rst_info();

    // And the monkey flips the switch. (Akiva Goldsman)
    Serial.println();
    Serial.println("*** zytQuadrat ***");
    Serial.println("Firmware: " + String(FIRMWARE_VERSION));
  memset(HostName, 0, sizeof(HostName));
  sprintf(HostName, "%s-%06X", PRODUCT_NAME, ESP.getChipId());
  memcpy(HostNameAp, HostName, sizeof(HostName));
  strcat(HostNameAp, "-AP");

#ifdef POWERON_SELFTEST
    renderer.setAllScreenBuffer(matrix);
    Serial.println("Set all LEDs to red.");
    writeScreenBuffer(matrix, RED, TEST_BRIGHTNESS);
    delay(2500);
    Serial.println("Set all LEDs to green.");
    writeScreenBuffer(matrix, GREEN, TEST_BRIGHTNESS);
    delay(2500);
    Serial.println("Set all LEDs to blue.");
    writeScreenBuffer(matrix, BLUE, TEST_BRIGHTNESS);
    delay(2500);
    Serial.println("Set all LEDs to white.");
    writeScreenBuffer(matrix, WHITE, TEST_BRIGHTNESS);
    delay(2500);
#endif

#ifdef ESP_LED
    Serial.println("Setting up ESP-LED.");
    pinMode(PIN_LED, OUTPUT);
    digitalWrite(PIN_LED, HIGH);
#endif

#ifdef MODE_BUTTON
    Serial.println("Setting up Mode-Button.");
    pinMode(PIN_MODE_BUTTON, INPUT_PULLUP);
    attachInterrupt(digitalPinToInterrupt(PIN_MODE_BUTTON), buttonModeInterrupt, FALLING);
#endif

#ifdef ONOFF_BUTTON
    Serial.println("Setting up Back-Button.");
    pinMode(PIN_ONOFF_BUTTON, INPUT_PULLUP);
    attachInterrupt(digitalPinToInterrupt(PIN_ONOFF_BUTTON), buttonOnOffInterrupt, FALLING);
#endif

#ifdef TIME_BUTTON
    Serial.println("Setting up Time-Button.");
    pinMode(PIN_TIME_BUTTON, INPUT_PULLUP);
    attachInterrupt(digitalPinToInterrupt(PIN_TIME_BUTTON), buttonTimeInterrupt, FALLING);
#endif

#ifdef PLUS_BUTTON
    Serial.println("Setting up Plus-Button.");
    pinMode(PIN_PLUS_BUTTON, INPUT_PULLUP);
    attachInterrupt(digitalPinToInterrupt(PIN_PLUS_BUTTON), buttonPlusInterrupt, FALLING);
#endif

#ifdef MINUS_BUTTON
    Serial.println("Setting up Minus-Button.");
    pinMode(PIN_MINUS_BUTTON, INPUT_PULLUP);
    attachInterrupt(digitalPinToInterrupt(PIN_MINUS_BUTTON), buttonMinusInterrupt, FALLING);
#endif

#ifdef BUZZER
    Serial.println("Setting up Buzzer.");
    pinMode(PIN_BUZZER, OUTPUT);
#endif

#ifdef SENSOR_DHT22
    Serial.println("Setting up DHT22.");
    dht.begin();
#endif

#ifdef SENSOR_BME280
    Serial.println(F("Setting up BME280."));
    bool bme_status;
    bme_status = bme.begin();
    if (!bme_status) {
      bme.begin(BME280_ADDRESS_ALTERNATE);
      if (!bme_status) {
        Serial.println(F("Could not find a valid BME280 sensor, check wiring, address!"));
      }
    }
#endif

#ifdef SENSOR_MCP9808
    Serial.println(F("Setting up MCP9808."));
    bool mcp_status;
    mcp_status = mcp.begin();
    if (!mcp_status) Serial.println(F("Could not find a valid MCP9808 sensor, check wiring, address!"));
#endif

#ifdef LDR
    Serial.print("Setting up LDR. ABC: ");
    settings.mySettings.useAbc ? Serial.println("enabled") : Serial.println("disabled");
    pinMode(PIN_LDR, INPUT);
#endif

#ifdef IR_RECEIVER
    Serial.println("Setting up IR-Receiver.");
    irrecv.enableIRIn();
#endif

    // Start WiFi and services
  wifiConnectHandler = WiFi.onStationModeGotIP(onWifiConnect);
  wifiDisconnectHandler = WiFi.onStationModeDisconnected(onWifiDisconnect);

    renderer.clearScreenBuffer(matrix);
    renderer.setSmallText("WI", TEXT_POS_TOP, matrix);
    renderer.setSmallText("FI", TEXT_POS_BOTTOM, matrix);
    writeScreenBuffer(matrix, WHITE, brightness);

    WiFi.setAutoConnect(true);
  WiFi.hostname(HostName);
  WiFi.setSleepMode(WIFI_NONE_SLEEP);
  setupWiFi();
  postWiFiSetup();

  Serial.println("Starting webserver.");
  setupWebServer();

  Serial.println("Starting updateserver.");
  httpUpdater.setup(&webServer);
  
#ifdef SYSLOGSERVER_SERVER
    Serial.println("Starting syslog.");
#ifdef APIKEY
    syslog.log(LOG_INFO, ";#;dateTime;roomTemperature;roomHumidity;outdoorTemperature;outdoorHumidity;sunriseTime;sunsetTime;ldrValue;errorCounterNTP;errorCounterDHT;errorCounterMCP;errorCounterBME;errorCounterOutdoorWeather;freeHeapSize;upTime");
#else
    syslog.log(LOG_INFO, ";#;dateTime;roomTemperature;roomHumidity;ldrValue;errorCounterNTP;errorCounterDHT;errorCounterMCP;errorCounterBME;freeHeapSize;upTime");
#endif
#endif

        Serial.println("Starting OTA service.");
#ifdef DEBUG
        ArduinoOTA.onStart([]()
        {
            Serial.println("Start OTA update.");
        });
        ArduinoOTA.onError([](ota_error_t error)
        {
            Serial.println("OTA Error: " + String(error));
            if (error == OTA_AUTH_ERROR) Serial.println("Auth failed.");
            else if (error == OTA_BEGIN_ERROR) Serial.println("Begin failed.");
            else if (error == OTA_CONNECT_ERROR) Serial.println("Connect failed.");
            else if (error == OTA_RECEIVE_ERROR) Serial.println("Receive failed.");
            else if (error == OTA_END_ERROR) Serial.println("End failed.");
        });
        ArduinoOTA.onEnd([]()
        {
            Serial.println("End OTA update.");
        });
#endif
        ArduinoOTA.setPassword(OTA_PASS);
        ArduinoOTA.begin();

#ifdef RTC_BACKUP
    RTC.begin();
    setSyncProvider(RTC.get);
    Serial.print("RTC Sync.");
    if (timeStatus() != timeSet) Serial.print(" FAIL!");
    Serial.println();
#ifdef DEBUG
    time_t tempRtcTime = RTC.get();
    Serial.printf("Time (RTC): %02u:%02u:%02u %02u.%02u.%04u\r\n", hour(tempRtcTime), minute(tempRtcTime), second(tempRtcTime), day(tempRtcTime), month(tempRtcTime), year(tempRtcTime));
#endif
#endif

    // Get the time!
    if (WiFi.isConnected())
    {
        // Set ESP (and RTC) time from NTP
        time_t tempNtpTime = ntp.getTime(ntpServer);
        if (tempNtpTime)
        {
            errorCounterNTP = 0;
            setTime(timeZone.toLocal(tempNtpTime));
#ifdef DEBUG
            Serial.printf("Time (NTP): %02u:%02u:%02u %02u.%02u.%04u (UTC)\r\n", hour(tempNtpTime), minute(tempNtpTime), second(tempNtpTime), day(tempNtpTime), month(tempNtpTime), year(tempNtpTime));
            Serial.printf("Drift (ESP): %d sec.\r\n", tempNtpTime - timeZone.toUTC(now()));
#endif
#ifdef RTC_BACKUP
            RTC.set(timeZone.toLocal(tempNtpTime));
#ifdef DEBUG
            Serial.printf("Drift (RTC): %d sec.\r\n", tempNtpTime - timeZone.toUTC(RTC.get()));
#endif
#endif
        }
        else
        {
            if (errorCounterNTP < 255)
                errorCounterNTP++;
#ifdef DEBUG
            Serial.printf("Error (NTP): %u\r\n", errorCounterNTP);
#endif
        }
    }
    else
    {
    }

    // Define a random time
    randomSeed(analogRead(A0));
    randomHour = random(0, 24);
    randomMinute = random(5, 56);
    randomSecond = random(5, 56);

    // Update room conditions
#if defined(RTC_BACKUP) || defined(SENSOR_DHT22) || defined(SENSOR_MCP9808) || defined(SENSOR_BME280)
    getRoomConditions();
#endif

    // print some infos
#ifdef DEBUG
    Serial.printf("Day on: %02u:%02u:00\r\n", hour(settings.mySettings.dayOnTime), minute(settings.mySettings.dayOnTime));
    Serial.printf("Night off: %02u:%02u:00\r\n", hour(settings.mySettings.nightOffTime), minute(settings.mySettings.nightOffTime));
    Serial.printf("Alarm1: %02u:%02u:00 ", hour(settings.mySettings.alarm1Time), minute(settings.mySettings.alarm1Time));
    settings.mySettings.alarm1 ? Serial.print("on ") : Serial.print("off ");
    Serial.println(settings.mySettings.alarm1Weekdays, BIN);
    Serial.printf("Alarm2: %02u:%02u:00 ", hour(settings.mySettings.alarm2Time), minute(settings.mySettings.alarm2Time));
    settings.mySettings.alarm2 ? Serial.print("on ") : Serial.print("off ");
    Serial.println(settings.mySettings.alarm2Weekdays, BIN);
    Serial.printf("Random time: %02u:%02u:%02u\r\n", randomHour, randomMinute, randomSecond);
    Serial.println("DEBUG is on.");
#else
    Serial.println("DEBUG is off.");
#endif

    lastDay = day() - 1;
    lastHour = hour();
    lastMinute = minute();
    lastSecond = second();

    setupFS();
    // Load Animationsliste
    getAnimationList();
    updateBrightness(true);
} // setup()

//*****************************************************************************
// Loop()
//*****************************************************************************

void loop()
{
    //*************************************************************************
    // Run once a day
    //*************************************************************************

    if (day() != lastDay)
    {
        lastDay = day();
        screenBufferNeedsUpdate = true;

#ifdef SHOW_MODE_MOONPHASE
        moonphase = getMoonphase(year(), month(), day());
#endif

#ifdef DEBUG
        Serial.printf("Uptime: %u days, %02u:%02u\r\n", int(upTime / 86400), hour(upTime), minute(upTime));
        Serial.printf("Free RAM: %u bytes\r\n", system_get_free_heap_size());
        Serial.printf("Moonphase: %u\r\n", moonphase);
#endif

        // Change color
        if (settings.mySettings.colorChange == COLORCHANGE_DAY)
        {
          colorNeedsChange = true;
        }
    }

    //*************************************************************************
    // Run once every hour
    //*************************************************************************

    if (hour() != lastHour)
    {
        lastHour = hour();
        screenBufferNeedsUpdate = true;

        // Change color
        if (settings.mySettings.colorChange == COLORCHANGE_HOUR)
        {
            colorNeedsChange = true;
        }

        // Hourly beep
#ifdef BUZZER
        if ((settings.mySettings.hourBeep == true) && (mode == MODE_TIME))
        {
            digitalWrite(PIN_BUZZER, HIGH);
            delay(25);
            digitalWrite(PIN_BUZZER, LOW);
#ifdef DEBUG
            Serial.println("Beep!");
#endif
        }
#endif

        //*********************************************************************
        // Run once every random hour (once a day)
        //*********************************************************************

        if (hour() == randomHour)
        {
            // Get updateinfo
#ifdef UPDATE_INFOSERVER
            if (WiFi.isConnected())
                getUpdateInfo();
#endif
        }

    }

    //*************************************************************************
    // Run once every minute
    //*************************************************************************

    if (minute() != lastMinute)
    {
        lastMinute = minute();
        screenBufferNeedsUpdate = true;

#if defined(RTC_BACKUP) || defined(SENSOR_DHT22) || defined(SENSOR_MCP9808) || defined(SENSOR_BME280)
        // Update room conditions
        getRoomConditions();
#endif

#ifdef BUZZER
        // Switch on buzzer for alarm 1
        if (settings.mySettings.alarm1 && (hour() == hour(settings.mySettings.alarm1Time)) && (minute() == minute(settings.mySettings.alarm1Time)) && bitRead(settings.mySettings.alarm1Weekdays, weekday()))
        {
            alarmOn = BUZZTIME_ALARM_1;
#ifdef DEBUG
            Serial.println("Alarm1 on.");
#endif
        }

        // Switch on buzzer for alarm 2
        if (settings.mySettings.alarm2 && (hour() == hour(settings.mySettings.alarm2Time)) && (minute() == minute(settings.mySettings.alarm2Time)) && bitRead(settings.mySettings.alarm2Weekdays, weekday()))
        {
            alarmOn = BUZZTIME_ALARM_2;
#ifdef DEBUG
            Serial.println("Alarm2 on.");
#endif
        }
#endif

#ifdef DEBUG
        time_t tempEspTime = now();
        Serial.printf("Time (ESP): %02u:%02u:%02u %02u.%02u.%04u\r\n", hour(tempEspTime), minute(tempEspTime), second(tempEspTime), day(tempEspTime), month(tempEspTime), year(tempEspTime));
#ifdef RTC_BACKUP
        time_t tempRtcTime = RTC.get();
        Serial.printf("Time (RTC): %02u:%02u:%02u %02u.%02u.%04u\r\n", hour(tempRtcTime), minute(tempRtcTime), second(tempRtcTime), day(tempRtcTime), month(tempRtcTime), year(tempRtcTime));
#endif
#endif

        // Set night- and daymode
        if ((hour() == hour(settings.mySettings.nightOffTime)) && (minute() == minute(settings.mySettings.nightOffTime)))
        {
#ifdef DEBUG
            Serial.println("Night off.");
#endif
            setMode(MODE_BLANK);
        }

        if ((hour() == hour(settings.mySettings.dayOnTime)) && (minute() == minute(settings.mySettings.dayOnTime)))
        {
#ifdef DEBUG
            Serial.println("Day on.");
#endif
            setMode(lastMode);

        }

        //*********************************************************************
        // Run once every random minute (once an hour) or if NTP has an error
        //*********************************************************************

        if ((minute() == randomMinute) || ((errorCounterNTP > 0) && (errorCounterNTP < 10)))
        {
            if (WiFi.isConnected())
            {
                // Set ESP (and RTC) time from NTP
                time_t tempNtpTime = ntp.getTime(ntpServer);
                if (tempNtpTime)
                {
                    errorCounterNTP = 0;
                    setTime(timeZone.toLocal(tempNtpTime));
#ifdef DEBUG
                    Serial.printf("Time (NTP): %02u:%02u:%02u %02u.%02u.%04u (UTC)\r\n", hour(tempNtpTime), minute(tempNtpTime), second(tempNtpTime), day(tempNtpTime), month(tempNtpTime), year(tempNtpTime));
                    Serial.printf("Drift (ESP): %d sec.\r\n", tempNtpTime - timeZone.toUTC(now()));
#endif
#ifdef RTC_BACKUP
                    RTC.set(timeZone.toLocal(tempNtpTime));
#ifdef DEBUG
                    Serial.printf("Drift (RTC): %d sec.\r\n", tempNtpTime - timeZone.toUTC(RTC.get()));
#endif
#endif
                }
                else
                {
                    if (errorCounterNTP < 255) errorCounterNTP++;
#ifdef DEBUG
                    Serial.printf("Error (NTP): %u\r\n", errorCounterNTP);
#endif
                }
            }
        }

        if (minute() == randomMinute)
        {
          updateOutdoorWeather();
        }

        //*********************************************************************
        // Run once every 5 minutes
        //*********************************************************************

        if (minute() % 5 == 0)
        {
#ifdef SYSLOGSERVER_SERVER
            // Write some data to syslog
            if (WiFi.isConnected())
            {
                time_t tempEspTime = now();
#ifdef APIKEY
                syslog.log(LOG_INFO, ";D;" + String(tempEspTime) + ";" + String(roomTemperature) + ";" + String(roomHumidity) + ";" + String(outdoorWeather.temperature) + ";" + String(outdoorWeather.humidity) + ";" \
                +String(hour(timeZone.toLocal(outdoorWeather.sunrise))) + ":" + String(minute(timeZone.toLocal(outdoorWeather.sunrise))) + ";" \
                + String(hour(timeZone.toLocal(outdoorWeather.sunset))) + ":" + String(minute(timeZone.toLocal(outdoorWeather.sunset))) + ";" + String(ldrValue)\
                    + ";" + String(errorCounterNTP) + ";" + String(errorCounterDHT) + ";" + String(errorCounterMCP) + ";" + String(errorCounterBME) + ";" + String(errorCounterOutdoorWeather) + ";" + String(ESP.getFreeHeap()) + ";" + String(upTime));
#else
                syslog.log(LOG_INFO, ";D;" + String(tempEspTime) + ";" + String(roomTemperature) + ";" + String(roomHumidity) + ";" + String(ldrValue)\
                    + ";" + String(errorCounterNTP) + ";" + String(errorCounterDHT) + ";" + String(errorCounterMCP) + ";" + String(errorCounterBME) + ";" + String(ESP.getFreeHeap()) + ";" + String(upTime));
#endif
#ifdef DEBUG
                Serial.println("Data written to syslog.");
#endif
            }
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

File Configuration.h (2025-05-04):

//*****************************************************************************
// Configuration.h
// See README.txt for help
//*****************************************************************************

#ifndef CONFIGURATION_H
#define CONFIGURATION_H

//*****************************************************************************
// Software settings
//*****************************************************************************

#define PRODUCT_NAME "Wortuhr"
#define WEBSITE_TITLE "Wortuhr"
//#define DEDICATION "The only reason for time is so that everything doesn't happen at once.<br>(Albert Einstein)"
#define WIFI_SETUP_TIMEOUT 50
#define WIFI_CONNECT_TIMEOUT 30000
#define BRIGHTNESS_TIMEOUT 1000
#define WIFI_AP_PASS "12345678"
#define OTA_PASS "1234"
#define NTP_DEFAULT_SERVER "pool.ntp.org"
#define SHOW_IP
#define WIFI_BEEPS

//#define NONE_TECHNICAL_ZERO
#define AUTO_MODECHANGE_TIME 60 // seconds
#define ALARM_LED_COLOR RED
//#define ABUSE_CORNER_LED_FOR_ALARM

//#define POWERON_SELFTEST
//#define SHOW_MODE_AMPM
#define SHOW_MODE_SECONDS
#define SHOW_MODE_WEEKDAY
#define SHOW_MODE_DATE
#define SHOW_MODE_MOONPHASE
#define SHOW_MODE_SUNRISE_SUNSET // works only if APIKEY is defined
#define SHOW_MODE_TEST
#define SHOW_MODE_SETTINGS

#define APIKEY
#define DEFAULT_LOCATION  "Achern, DE"

//--------------
#define MOOD_INTERVAL_MIN 300
#define MOOD_INTERVAL_MAX 4000

#define MIN_ANI_DURATION 2500

#ifdef SHOW_MODE_SETTINGS
#define SETTINGS_TITLE_TIMEOUT 2500
#endif

//#define LANGUAGE_EN
#define LANGUAGE_DE
//#define LANGUAGE_FR
//#define LANGUAGE_IT
//#define LANGUAGE_ES
//#define LANGUAGE_NL

//*****************************************************************************
// Timezone
//*****************************************************************************

//#define TIMEZONE_IDLW  // IDLW  International Date Line West UTC-12
//#define TIMEZONE_SST   // SST   Samoa Standard Time UTC-11
//#define TIMEZONE_HST   // HST   Hawaiian Standard Time UTC-10
//#define TIMEZONE_AKST  // AKST  Alaska Standard Time UTC-9
//#define TIMEZONE_USPST // USPST Pacific Standard Time (USA) UTC-8
//#define TIMEZONE_USMST // USMST Mountain Standard Time (USA) UTC-7
//#define TIMEZONE_USAZ  // USAZ  Mountain Standard Time (USA) UTC-7 (no DST)
//#define TIMEZONE_USCST // USCST Central Standard Time (USA) UTC-6
//#define TIMEZONE_USEST // USEST Eastern Standard Time (USA) UTC-5
//#define TIMEZONE_AST   // AST   Atlantic Standard Time UTC-4
//#define TIMEZONE_BST   // BST   Eastern Brazil Standard Time UTC-3
//#define TIMEZONE_VTZ   // VTZ   Greenland Eastern Standard Time UTC-2
//#define TIMEZONE_AZOT  // AZOT  Azores Time UTC-1
//#define TIMEZONE_GMT   // GMT   Greenwich Mean Time UTC
#define TIMEZONE_CET     // CET   Central Europe Time UTC+1
//#define TIMEZONE_EST   // EST   Eastern Europe Time UTC+2
//#define TIMEZONE_MSK   // MSK   Moscow Time UTC+3 (no DST)
//#define TIMEZONE_GST   // GST   Gulf Standard Time UTC+4
//#define TIMEZONE_PKT   // PKT   Pakistan Time UTC+5
//#define TIMEZONE_BDT   // BDT   Bangladesh Time UTC+6
//#define TIMEZONE_JT    // JT    Java Time UTC+7
//#define TIMEZONE_CNST  // CNST  China Standard Time UTC+8
//#define TIMEZONE_HKT   // HKT   Hong Kong Time UTC+8
//#define TIMEZONE_PYT   // PYT   Pyongyang Time (North Korea) UTC+8.5
//#define TIMEZONE_CWT   // CWT   Central West Time (Australia) UTC+8.75
//#define TIMEZONE_JST   // JST   Japan Standard Time UTC+9
//#define TIMEZONE_ACST  // ACST  Australian Central Standard Time UTC+9.5
//#define TIMEZONE_AEST  // AEST  Australian Eastern Standard Time UTC+10
//#define TIMEZONE_LHST  // LHST  Lord Howe Standard Time UTC+10.5
//#define TIMEZONE_SBT   // SBT   Solomon Islands Time UTC+11
//#define TIMEZONE_NZST  // NZST  New Zealand Standard Time UTC+12

//*****************************************************************************
// Hardware settings
//*****************************************************************************

#define BOARD_DEFAULT
//#define BOARD_QWF_V1_2
//#define BOARD_QWF_MINI_V1_1
//#define BOARD_QWF_V2_0

#ifdef BOARD_DEFAULT
#define ESP_LED
//#define SENSOR_DHT22
//#define SENSOR_MCP9808
//#define SENSOR_BME280
//#define RTC_BACKUP
#define LDR
//#define BUZZER
//#define IR_RECEIVER

//#define ONOFF_BUTTON
//#define MODE_BUTTON
//#define TIME_BUTTON
//#define PLUS_BUTTON
//#define MINUS_BUTTON

// Pin Definition ESP8266 (Wemos D1 mini)
#define PIN_IR_RECEIVER  16 // D0 (no interrupt)
//#define PIN_WIRE_SCL     05 // D1 SCL
//#define PIN_WIRE_SDA     04 // D2 SDA
#define PIN_MODE_BUTTON  00 // D3 LOW_Flash
#define PIN_LED          02 // D4 ESP8266_LED
#define PIN_BUZZER       14 // D5
#define PIN_DHT22        12 // D6
#define PIN_LEDS_CLOCK   13 // D7
#define PIN_LEDS_DATA    15 // D8
#define PIN_LDR          A0 // ADC
#define PIN_TIME_BUTTON  01 // TXD0
#define PIN_ONOFF_BUTTON 03 // RXD0
// GPIO 06 to GPIO 11 are
// used for flash memory databus
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

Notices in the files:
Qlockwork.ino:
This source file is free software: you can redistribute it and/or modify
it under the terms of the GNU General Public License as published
